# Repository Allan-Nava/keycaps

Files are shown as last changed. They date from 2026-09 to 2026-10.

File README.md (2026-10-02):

# keycaps

Replacement keycaps for mechanical keyboards, modelled parametrically in
OpenSCAD, validated geometrically before anything gets sliced, and documented
with the provenance of every single dimension.

## Why it is built this way

Replacement keycaps fail for boring reasons: a stem 0.1 mm too tight, a
stabiliser hook 0.5 mm too high, a skirt that rubs the switch housing. So the
rule here is:

* **every dimension carries a provenance tag** — `[SRC]` from a source,
  `[DER]` derived from one, `[EST]` closest standard value, `[FIT]` fit-critical
  *and* unverifiable online, so it has to be measured off the original part;
* **nothing is asserted that was not found** — if a number could not be sourced
  it is marked as an estimate, never dressed up as confirmed;
* **checks are boolean probes, not eyeballing** — a solid shaped like a real MX
  cross is pushed into the socket and the interference volume is measured;
* **the drawing is generated from the rendered solid**, and the Python tooling
  reads its dimensions back out of the render, so neither can drift from the
  model.

## Layout

```
lib/keycap_common.scad      shared geometry: shell, dish, sculpt, MX cross
                            socket, Costar hook, ribs, relief legends
tools/build_and_validate.py render + write the print-ready STL + 20 checks
tools/make_drawing.py       dimensioned 4-view drawing from the solid
tools/scadparams.py         reads ##PARAM echoes back out of a render

<keyboard>/<key>.scad       parameters + provenance for one key
<keyboard>/<key>.stl        production STL, already in print orientation
<keyboard>/<key>-drawing.*  svg / pdf / png
<keyboard>/README.md        provenance, critical dimensions, print settings
<keyboard>/VALIDATION-<key>.txt   output of the last validation run
```

## Keyboards

| keyboard | key | status |
|---|---|---|
| [`ozone-strike-battle`](ozone-strike-battle/) | left Shift — **ISO 1.25u** and ANSI 2.25u | **done** — all checks pass. ISO prints as-is; the ANSI one has one `[FIT]` dimension to measure first |
| [`asus-rog-falchion-ace`](asus-rog-falchion-ace/) | left Shift ISO 1.25u, G, ↑ — ITA layout | **done** — all checks pass; profile is estimated, nothing was measured |

## Usage

```bash
python3 tools/build_and_validate.py ozone-strike-battle/left-shift-iso.scad
python3 tools/make_drawing.py       ozone-strike-battle/left-shift-iso.scad
```

Or `make` (builds and validates everything, then the drawings).

### Requirements

* `openscad` with the manifold backend. On macOS the stable cask is disabled
  (Gatekeeper), so use the snapshot: `brew install --cask openscad@snapshot`
* Python: `trimesh manifold3d numpy rtree matplotlib`

```bash
python3 -m venv .venv && .venv/bin/pip install trimesh manifold3d numpy rtree matplotlib
```

## Printed

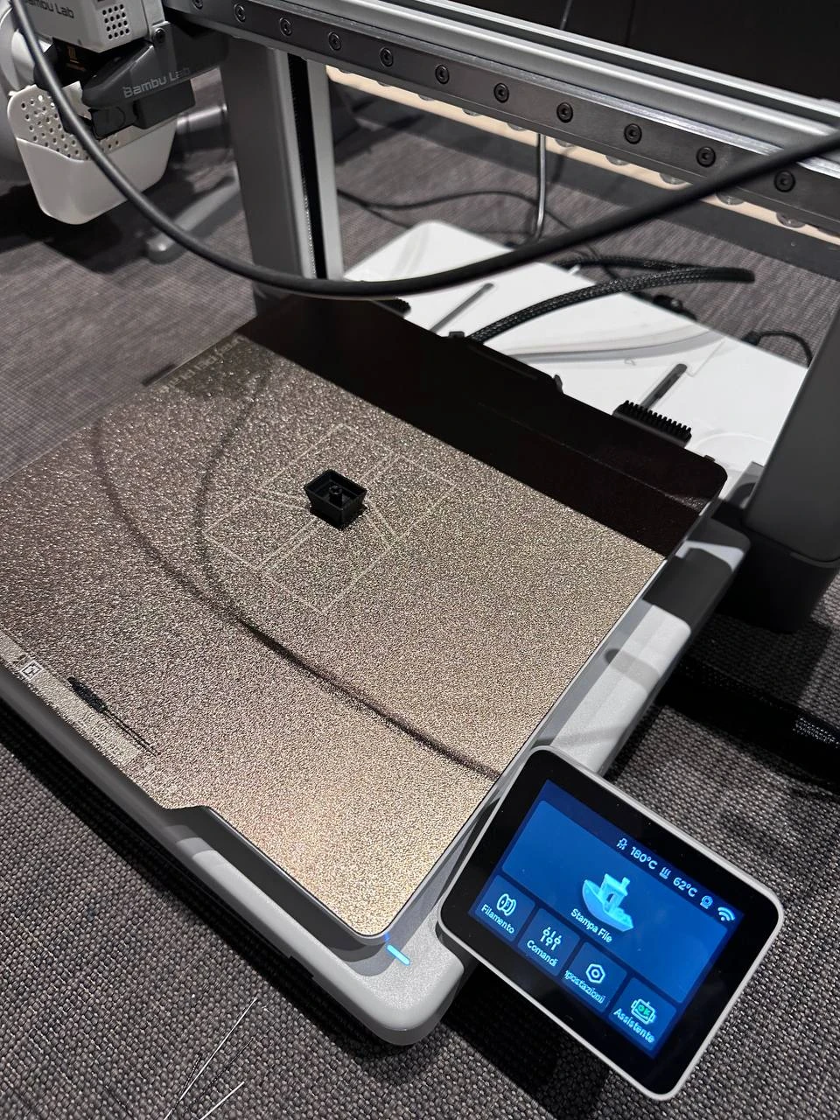
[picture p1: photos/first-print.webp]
first print


The first model off the plate, 2026-10-02. It sliced with no support in the
committed orientation, which is the part the geometric checks predicted.

What this photo does **not** prove is the part that matters: whether it seats
on a real switch. Until a cap has been pushed onto one, the stem clearances
are still the estimates the provenance tables say they are. See
[`photos/`](photos/) for what a print does and does not establish.

## The catalogue

**<https://allan-nava.github.io/keycaps/>** — every model with its dimensions,
its weight in PLA, its drawing and a direct STL download.

The page is generated by [`tools/make_site.py`](tools/make_site.py) from the
JSON the validator writes, so it cannot state a dimension the checks did not
measure, and it only deploys after `validate` is green.

## CI

Three workflows.

**[`validate`](.github/workflows/validate.yml)** is the merge gate. It discovers
every `<keyboard>/<key>.scad` by itself (no list to maintain), renders each one
on a matrix job and runs the full check suite, then verifies that the
**committed STL still matches the model** — which is what catches "edited the
.scad, forgot to regenerate". That last comparison is on the bounding box and
the volume, not on bytes: tessellation and font substitution differ between a
Mac and a runner, so a byte compare would be permanently red. A `repo hygiene`
job checks in parallel that every key has an STL, a validation report and a
README. On a green push to `main` the printable files go up as a single
downloadable artifact, so nobody needs OpenSCAD to get them.

**[`pages`](.github/workflows/pages.yml)** builds and publishes the
catalogue, and refuses to run when `validate` failed: publishing a keycap that
does not pass its own checks would be worse than publishing nothing.

**[`self-test`](.github/workflows/selftest.yml)** exists because a check that
cannot fail is decoration. It breaks a known-good keycap on purpose — socket
bored out, cap wider than its own pitch, walls thickened past the switch,
Costar bore under the wire diameter, socket undersized — and asserts that *the
specific check meant to catch that defect* is the one reporting FAIL, not
merely that something went wrong. It runs whenever `tools/` or `lib/` changes,
which is where a check can quietly stop working.

The drawings are byte-reproducible: matplotlib is told not to stamp a creation
date, so regenerating a drawing that did not change produces no diff, and "is
the committed artefact current" stays an answerable question.

Run both locally:

```bash
python3 tools/build_and_validate.py --check <keyboard>/<key>.scad
python3 tools/repo_lint.py
python3 tools/selftest.py
```

Ubuntu ships OpenSCAD 2021.01, which predates `--backend=manifold`, so CI
installs a dated snapshot AppImage — pinned for reproducibility, with a warned
fallback to the newest when that snapshot rotates off the server. See
[`.github/scripts/install-openscad.sh`](.github/scripts/install-openscad.sh).

## Adding a key

1. `cp ozone-strike-battle/left-shift-iso.scad <keyboard>/<key>.scad` and strip it
   back to the parameters that actually differ. With more than one key on the
   same board, put the shared parameters in `<keyboard>/profile.inc.scad` —
   files matching `*.inc.scad` are not treated as keys by the tools.
2. Override only what you know. Anything left at the library default is an
   estimate by definition — tag it `[EST]` and say so in the README.
3. Run the validator. It refuses to pass on an unimplemented stabiliser style
   rather than silently skipping the check.
4. Write `<keyboard>/README.md` with the provenance table, and list what could
   **not** be verified. That section is the point of the repo.

## Two OpenSCAD traps this repo walked into

**An included file's *variable* cannot be referenced from an assignment in the
including file.** OpenSCAD reports `Ignoring unknown variable` and leaves
`undef`, which then propagates silently through the whole model. A *function*
from the same include resolves fine, which is why per-row values are exposed as
`fa_h(row)` / `fa_tilt(row)` rather than `FA_R4_H`. Module arguments
(`text(font = fa_font())`) are evaluated later and are also fine.

**A relief legend whose outline is tangent to the stem boss's cylindrical seam
produces sliver faces and a non-manifold mesh** — clean in OpenSCAD's own
report, broken on reload. That is why `stem_top_gap` stops the boss 0.90 mm
below the top surface: the boss stays fused to the roof and its seam never
reaches the surface where a legend sits.

## Licence

[MIT](LICENSE) — the OpenSCAD sources, the Python tooling and the generated
STLs alike. Print them, sell the prints, fork the lot; just keep the notice.

**No warranty, and that matters here more than usual**: several dimensions in
every model are estimates, and each keyboard's README says exactly which ones.
Test-fit a print on a spare switch before committing to a set.

## Stabiliser styles

`lib/keycap_common.scad` implements:

* `"none"` — 1u keys and anything unstabilised.
* `"costar"` — wire stabiliser with integrated hooks, so the original white
  Costar inserts are not needed. Used by the Strike Battle.

`"cherry"` (clip-in plastic stabiliser stems, what most modern boards use) is
deliberately **not implemented**: the housing and stem dimensions have to be
measured or sourced first. A wrong stabiliser stem binds the key, so it is
better to have nothing there than a plausible guess.

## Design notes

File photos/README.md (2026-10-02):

# Physical evidence

Everything else in this repo is geometry: a solid is rendered, boolean probes
are pushed into it, and the numbers are recorded. That catches a great deal —
a socket that would not accept an MX cross, a cap wider than its own key
pitch, an overhang that would need support — and it cannot catch anything
that only exists once plastic cools.

So this directory is for photographs of the models as actually printed, kept
separate from the validation output on purpose. **A photo is not a check.**
It is the thing a check cannot be.

## What a print proves, and what it does not

| | |
|---|---|
| it printed | the geometry is sliceable, the orientation works, no support was needed |
| it looks right | the profile, the dish and the legend are what the drawing said |
| **it fits** | **only confirmed by pushing it onto a real switch** |
| it survives | only confirmed by typing on it for a while |

The third row is the one that matters, and it is the one a photograph of a
build plate cannot answer. Until a cap has been seated on a switch, the
tolerances in `cross_clr_w` / `cross_clr_t` are still estimates — see the
provenance tables in each keyboard's README.

## Index

| photo | model | printed on | fit confirmed |
|---|---|---|---|
| [`first-print.webp`](first-print.webp) | 1u cap, Bambu Lab, black filament | 2026-10-02 | not yet |

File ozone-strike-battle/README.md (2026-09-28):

# Ozone Strike Battle — replacement LEFT SHIFT keycap

Cherry MX cross stem, OEM-like sculpt, designed for FDM in PLA / PETG.
**Two variants, and they are not interchangeable — pick by your layout:**

| variant | file | size | stabiliser | fits |
|---|---|---|---|---|
| **ISO** | `left-shift-iso.stl` | **1.25u**, 22.85 × 18.10 × 11.39 | **none** | ITA / UK / DE — a `<>` or `\|` key sits next to the left Shift, and the Enter is the tall L |
| ANSI | `left-shift-ansi.stl` | 2.25u, 41.90 × 18.10 × 11.39 | Costar wire, integrated hooks | US — Z is directly next to the left Shift, and the Enter is a flat 2.25u bar |

The board this was built for is an **ISO Italian** Strike Battle. ITA, UK and DE
share the same 1.25u left Shift — only the glyph on the key next to it differs
(`<>` on ITA, `\|` on UK) — so the ISO cap covers all three.

Look at your own board before printing. On an ISO keyboard the left Shift is
split into a 1.25u Shift plus the extra `<>` key, so it is short and carries no
stabiliser at all; on ANSI it is one 2.25u key on a 2u Costar wire.

The **ISO cap is the simpler of the two**: no stabiliser means the one
fit-critical, unverifiable dimension of the ANSI cap (§1) does not exist for it.
If you are on ISO, you can print straight away.

| file | what it is |
|---|---|
| `left-shift-iso.*` / `left-shift-ansi.*` | STL, parametric source, dimensioned drawing, renders |
| `VALIDATION-left-shift-iso.txt` / `-ansi.txt` | validation output — **ALL CHECKS PASSED** for both |

Rebuild:

```bash
python3 ../tools/build_and_validate.py left-shift-iso.scad
python3 ../tools/make_drawing.py       left-shift-iso.scad
```

Everything below — provenance, profile, print settings — applies to both caps.
The parts that are specific to the Costar stabiliser are marked as such and are
simply absent from the ISO variant.

---

## 1. ANSI variant only — the one dimension I could not verify

*(The ISO 1.25u cap has no stabiliser, so none of this section applies to it.)*

**`wire_z = 4.20 mm`** — the height of the Costar wire stub above the bottom rim
of the keycap. This is the single fit-critical dimension that is **not documented
anywhere online**, not for the Strike Battle and not for Costar stabilisers in
general. I did not find a drawing, a datasheet or a measured teardown.

If it is wrong, the Shift key will bind or the wire will not seat.

**Measure it on your original cap** (or on the keyboard, with the stabiliser
installed and the cap off): the distance from the plane of the keycap's bottom
rim to the centre of the horizontal wire stub. Then edit one line:

```openscad
wire_z       = 4.20;    // <- your measurement
```

and re-render. Everything else in the stabiliser interface (bore, throat,
lead-in, block) follows from it automatically.

Two related things I also could not confirm, and how the design sidesteps them:

* **Whether the original Ozone cap uses separate white Costar inserts or moulded-in
  hooks.** The Deskthority Costar page shows Filco inserts but gives no
  dimensions, and no Strike Battle underside teardown photo with measurements
  exists that I could find. → This design uses **integrated hooks**, so you do
  not need the original inserts at all. If you would rather reuse them, the hook
  block is a single module in the `.scad` and can be replaced with a pocket.
* **Which way the wire stub points** (inwards, towards the key centre, or
  outwards). → The bore is a **through-hole along X across the whole hook block**,
  so it works either way.

---

## 2. Critical dimensions

All in mm. Origin = key centre, z = 0 at the bottom rim of the skirt, +Y towards
the back of the keyboard.

### Outside

| dimension | value | tag |
|---|---|---|
| 1u pitch | 19.05 | SRC |
| key size | 2.25u → 42.8625 pitch | SRC |
| body width (plastic) | **41.90** | DER |
| body depth (plastic) | **18.10** | DER |
| gap to Caps Lock / Z | 0.48 per side | DER |
| height at the key centre (top of the dish) | 9.60 | EST |
| overall height (highest point, at the back edge) | 11.39 *(measured on the solid)* | DER |
| row tilt (back edge higher) | 6° | EST |
| top plate | 37.70 × 13.90 | EST |
| side draft | 2.10 per side over 10.05 → ~11.8° | EST |
| corner radius, skirt / top | R1.20 / R2.60 | EST |
| top edge chamfer | 0.60 | EST |
| dish | cylindrical, R28, 1.05 deep, axis along X | EST |
| legend | embossed up-arrow, 0.45 high, at x = −13.5 | EST |

### Shell

| dimension | value | tag |
|---|---|---|
| side wall | 1.55 | EST |
| skirt wall (below z = 4.20, blending back over 0.80) | 1.15 | EST |
| roof under the dish | 1.70 | EST |
| diagonal ribs | 4 × 1.20 thick, starting at z = 5.00 | EST |

The skirt is deliberately thinner than the rest: it keeps the interior at least
as roomy as a stock OEM cap all the way around the switch housing (validated —
see §4).

### Cherry MX stem

| dimension | value | tag |
|---|---|---|
| cross, switch side | 4.10 × 1.17 | SRC |
| socket, as modelled | **4.22 × 1.39** | DER (SRC + tolerance) |
| FDM clearance added | +0.12 across, +0.22 through | EST |
| socket depth | 4.30 (MX stem is ~3.7 tall) | EST / SRC |
| chamfered lead-in at the mouth | 0.45 | EST |
| stem boss OD | 5.60 (stock ≈ 5.5) | EST |
| boss bottom face | z = 0.50 | EST |

### Costar stabiliser

| dimension | value | tag |
|---|---|---|
| mount spacing | 1.25u = **23.8125** (±11.90625) | SRC → DER |
| wire diameter assumed | 1.30 (quoted 1.2 + margin) | SRC / EST |
| bore | Ø1.65 (0.35 diametral clearance), through the block along X | EST |
| wire height above the rim | **4.20** | **FIT — unverified** |
| snap throat | 1.20 wide, straight for 0.60 below the bore, then flared +1.6 | EST |
| hook block | 6.00 (X) × 5.50 (Y), bottom face at z = 2.60 | EST |

---

## 3. Where each number came from

### Taken from a source

* **19.05 mm per unit; left Shift = 2.25u; left Shift stabiliser = 2u** —
  [Omnitype keycap sizes](https://intercom.help/omnitype/en/articles/5121683-keycap-sizes).
  That page gives no millimetres, only units.
* **2u stabiliser mounts are 1.25u apart** → 1.25 × 19.05 = **23.8125 mm**, i.e.
  ±11.90625 from the stem. Stated as "stabilizers are the same for 2u, 2.25u and
  2.75u keys with 1.25u between mounts" in the Cherry MX plate-measurement
  discussion on [Deskthority](https://deskthority.net/viewtopic.php?t=20144).
* **Cherry MX cross: 4.1 mm wide, 1.17 mm thick** — the Cherry MX drawing, as
  cited by the [MX keycap tolerance test](https://www.thingiverse.com/thing:4397634)
  and the [Cherry MX mount thread](https://deskthority.net/viewtopic.php?t=11183).
  The same sources list the common keycap-side variants 4.0 × 1.0 (Signature
  Plastics) and 4.1 × 1.35.
* **MX stem ~3.7 mm tall, 4.0 mm travel** — [Telcontar KBK, Cherry MX](https://telcontar.net/KBK/Cherry/MX).
* **This keyboard specifically** — the [Test-Gear review](https://www.test-gear.pl/testy-i-recenzje/klawiatury/ozone-strike-battle/):
  Cherry MX switches, **Costar-type stabilisers under the long keys**, ABS
  keycaps, "cylindrical shape with rounded edges", keycap **heights 9–11 mm**,
  **right Shift measured at 51 mm**, **spacebar at 118 mm**. Plus the
  [Ozone specification page](https://ozonegaming.com/en/pages/especificaciones-strike-battle):
  87 keys, ABS 94HB keycaps, backlight with brightness steps (so there *is* an
  LED in the switch's north window to clear).
* **Costar 2u wire quoted at 1.2 mm diameter** — from a stabiliser listing found
  via search. Single, weak source; treated as 1.30 with margin.
* **FDM tolerance guidance: cut-outs need ~0.1 mm added** — the MX tolerance
  test above (0.05 for SLA, >0.1 for FDM).

### Derived from those

* **41.90 body width.** The review's 51 mm right Shift (2.75u pitch = 52.3875)
  and 118 mm spacebar (6.25u pitch = 119.0625) both fit an inter-cap gap of
  ≈1.0 mm: 52.3875 − 1.0 = 51.39 → "51", and 119.0625 − 1.0 = 118.06 → "118".
  A gap of 0.85 (the usual 18.2 mm 1u body) would give 51.5 and 118.2, which
  rounds to 52 and 118 — a worse fit to the measurements. I used 0.96, giving
  41.90 for 2.25u. The review's figures are ruler measurements, so treat this as
  ±0.3 mm; it only affects the gap to Caps Lock and Z, not the fit.
* **18.10 body depth** — same reasoning on the 1u axis (gap 0.95).
* **±11.90625 stabiliser positions** — 1.25u/2.
* **4.22 × 1.39 socket** — the 4.10 × 1.17 cross plus FDM clearance.

### Estimated (closest standard value, not verified for this board)

Everything tagged `[EST]` in §2: the sculpt (heights, tilt, taper, radii, dish),
all wall and roof thicknesses, the rib and hook-block geometry, socket depth,
stem boss diameter, and the print tolerances. The only anchor for the sculpt is
the review's "9–11 mm" height range and "cylindrical" top, which the model
matches (9.60 at the dish centre, 11.60 at the back edge, cylindrical R28 dish).

OEM row heights are quoted inconsistently across vendor pages (10.3–13.3 mm
depending on who is measuring what), so I did not use them.

### Cannot be verified from online documentation

1. **`wire_z` = 4.20** — see §1. The one that matters.
2. Whether the original cap uses **separate Costar inserts** and, if so, their
   socket dimensions. No dimensioned source exists.
3. The **direction of the wire stub**. Worked around with a through-bore.
4. The exact **Cherry MX top-housing envelope above the plate** and the LED
   height. Because of this, the switch-clearance check is *relative* (see §4)
   rather than against an invented envelope.

---

## 4. Validation (all automated, see `VALIDATION.txt`)

Every check is a boolean probe against the rendered solid, not a visual check.

```
mesh        watertight, single closed solid, euler = 2, volume 2731.7 mm^3
size        41.903 x 18.100 x 11.39 ; fits the 2.25u x 1u pitch with
            0.48 mm per side to Caps Lock / Z and 0.47 mm front / back
stem        a nominal 4.10 x 1.17 MX cross enters with zero interference;
            a 4.40 x 1.47 probe does clash -> the socket is not oversized;
            socket centroid X = 0.000, Y = 0.000 -> centred
Costar      bores clear at x = +-11.90625 ; throat (1.20) open to the underside ;
            seated wire free to move +-0.15 mm inside the bore ;
            wire arm clears the whole cavity from |x| = 3.2 to 18.5 (misses the
            stem boss, the ribs and the walls) ; 0.02 mm^3 of intentional
            throat interference = a light snap
switch/LED  interior never tighter than a stock OEM cap (18.20 outer, 1.20 wall,
            same draft) anywhere from z = 0.2 to 5.0 -> worst margin -0.00 mm ;
            the north LED column (4 x 2.2 mm at y = 2.9..5.1, 7 mm tall) is clear
printing    sits flat on z = 0 ; first layer is the top-plate rim, not a point ;
            4.6 mm^2 of true overhang (the two bore roofs, 6 mm wide bridges) ;
            532 mm^2 of dish bridged over the bed, anchored all round ;
            1373 mm^2 of drafted wall at <= 12.6 deg from vertical
```

The switch-clearance check is deliberately **relative**: since the MX housing
envelope above the plate is not reliably documented, the model is required to be
no tighter anywhere than a stock OEM 1u cap's interior. It passes at every height
from 0.2 to 5.0 mm.

---

## 5. Printing

The STL is already oriented: **top plate flat on the bed, open side up**. Nothing
needs support — the dish is a 1.05 mm deep pocket sitting directly on the bed and
is bridged from its own rim, and the two wire bores are 6 mm bridges.

### PLA

| setting | value | why |
|---|---|---|
| **layer height** | **0.12 mm** (0.16 acceptable) | the cross socket is 1.39 mm through — thin layers keep it dimensionally honest |
| first layer | 0.20 mm | rim-only contact |
| **wall count** | **3** (0.4 nozzle, 0.42 width ≈ 1.26 mm) | matches the 1.15 mm skirt and the 1.55 mm wall without leaving gaps; 4 walls would over-stuff the skirt |
| **infill** | **100 %** | the part is nearly all perimeters; 100 % only fills the stem boss and hook blocks, where the strength is needed, and costs ≈2.7 cm³ total |
| top / bottom layers | 5 / 5 | |
| nozzle / bed | 205–215 °C / 60 °C | |
| cooling | 100 % from layer 3 | |
| supports | **none** | |
| brim | 5 mm, or a raft if your first layer is fussy | the bed contact is only the top-plate rim |
| seam | aligned, placed at a rear corner | keeps the visible top clean |
| horizontal expansion / XY compensation | 0 | the clearances are already in the model |

**PETG:** same, but 230–245 °C, 50 % cooling, and add 0.05 mm to
`cross_clr_w` / `cross_clr_t` — PETG swells more on the way out of the nozzle.

### Test fit first

Print the model once and try the stem on a spare switch before committing to the
stabiliser geometry.

* **too tight** → raise `cross_clr_w` / `cross_clr_t` by 0.05
* **too loose / wobbles** → lower them by 0.05
* **wire will not snap in** → raise `throat_w` toward `stab_wire_d`
* **wire rattles** → lower `bore_clr` to 0.25

### Fitting

1. Press the cap onto the switch far enough to locate the stem.
2. Line the two wire stubs up with the throats and push straight down — each
   stub snaps up into its bore.
3. Press home on the stem last.

To remove, pull evenly from both ends, not from one corner.

---

## 6. Deliberate departures from the original

* **Integrated Costar hooks instead of separate inserts** — you do not need the
  original white clips, and it removes an unverifiable set of socket dimensions.
* **Stem boss Ø5.60 instead of the stock ≈5.5** — a little more meat around the
  cross for FDM, while still clearing the in-switch LED at the north face.
* **Thinner skirt (1.15) than the upper wall (1.55)** — keeps the interior at
  least as roomy as a stock cap around the switch housing while leaving a wall
  thick enough to print at 3 perimeters higher up.
* **Embossed arrow instead of the original's laser-cut legend** — a single-colour
  FDM print cannot reproduce a dye-sub two-layer legend. Set
  `legend_arrow = false` for a blank cap.
* Functional compatibility was prioritised over cosmetic similarity throughout,
  as requested.

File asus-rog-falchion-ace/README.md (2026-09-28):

# ASUS ROG Falchion Ace — replacement keycaps (ISO/ITA)

Three keys, none of them stabilised: **left Shift (ISO 1.25u)**, **G (1u)** and
**↑ (1u)**. MX-compatible cross stem, Cherry-like sculpt, for FDM in PLA/PETG.

| key | file | size | row | overall height | STL |
|---|---|---|---|---|---|
| left Shift | `left-shift.scad` | 1.25u | ZXCV | 9.97 mm | `left-shift.stl` |
| ↑ | `arrow-up.scad` | 1u | ZXCV | 9.86 mm | `arrow-up.stl` |
| G | `g.scad` | 1u | home (ASDF) | 8.50 mm | `g.stl` |

All three pass every check — `VALIDATION-<key>.txt`. Shared parameters live in
`profile.inc.scad`; the geometry itself is in [`../lib/keycap_common.scad`](../lib/keycap_common.scad).

```bash
python3 ../tools/build_and_validate.py left-shift.scad
python3 ../tools/make_drawing.py       left-shift.scad
```

---

## 1. What is confirmed, and by what

### From the product photo supplied by the user

The user's board is the **Italian** one. The photo they supplied happens to show
the DE/QWERTZ variant, which they confirmed matches their layout physically —
and it does: ITA and DE differ only in which glyphs are printed on *other* keys
(QWERTZ vs QWERTY, Ü Ö Ä vs Ì Ò À), never in key sizes or positions. For the
three keys modelled here — ⇧, G and ↑ — the two layouts are identical.

The photo settles three things a spec sheet does not:

* **left Shift is 1.25u**, with the extra ISO `<>|` key next to it — so, unlike
  the ANSI 2.25u left Shift in `../ozone-strike-battle/`, **it is not
  stabilised**;
* **↑ sits in the ZXCV row**, to the right of the right Shift, so it takes that
  row's sculpt, not the bottom row's;
* legends on the alphas are centred, and the board is ISO (tall L-shaped Enter).

### From sources

* **ROG NX stem is MX-compatible**: ASUS states the "standard cross-shaped stem
  design ensures compatibility with most keycaps", so the Cherry MX cross
  (4.10 × 1.17) applies. [ROG NX switch page](https://rog.asus.com/content/rog-keyboard-switch/)
* **No LED enters the keycap.** Per-key RGB comes from "centrally placed RGB
  LEDs" on the PCB, shining through the switch's **hollow stem** and its
  transparent polycarbonate upper housing. So there is nothing to clear inside
  the cap — `led_clear_h = 0`, and the validator says so explicitly instead of
  silently skipping. [ROG NX switch page](https://rog.asus.com/content/rog-keyboard-switch/)
* **Cherry profile, PBT doubleshot**, "mid-height keycaps". [ASUS product page](https://rog.asus.com/keyboards/keyboards/compact/rog-falchion-ace-model/),
  [review](https://basic-tutorials.com/reviews/peripherals/asus-rog-falchion-ace/)
* **65 %, 68 keys, 306 mm long.** ASUS product page.
* Cherry MX cross 4.10 × 1.17: the Cherry drawing, via the
  [MX tolerance test](https://www.thingiverse.com/thing:4397634) and
  [Deskthority](https://deskthority.net/viewtopic.php?t=11183).

---

## 2. The profile — how the heights were arrived at

**This is the weak part of the model, and it is cosmetic, not fit-critical.**

ASUS publishes no keycap drawing. The public Cherry-profile guides contradict
each other badly: one gives R1 9.81 / R2 7.85 / R3 7.22 / R4 8.59 mm with the
home row lowest and calls the sculpt spherical (it is cylindrical); another
gives 9.4 / 9.0 / 8.75 / 8.1 mm monotonically decreasing, with the home row
*not* lowest. They cannot both be right and I could not resolve which is.

So the numbers here are built from the one claim both sources agree on —
**Cherry is 1–2 mm lower than OEM across all rows** — plus this repo's own
validated OEM cap:

* `../ozone-strike-battle/left-shift-ansi` is a validated OEM ZXCV-row cap at
  **11.39 mm** overall → Cherry ZXCV ≈ 11.39 − 1.5 = **~9.9 mm**. Modelled:
  9.97 (1.25u) / 9.86 (1u).
* The **row-to-row delta** (1.37 mm between ZXCV and home) and the **tilts**
  (12° / 5°) come from the internally coherent source — the one where the home
  row is lowest and the tilt grows away from it, which is how a sculpted
  profile actually behaves. Home row → **8.50 mm** overall.

Every profile number is therefore `[EST]`. If you ever get a caliper on an
original cap, `profile.inc.scad` has `fa_h(row)` and `fa_tilt(row)` at the top —
two lines.

Same for the body size: no measurement exists for this board, so 1u is
**18.10 × 18.10 mm** (the common value for Cherry-profile sets), leaving 0.47 mm
of gap per side inside the 19.05 pitch.

---

## 3. Critical dimensions

mm, origin at the key centre, z = 0 at the bottom rim, +Y towards the back.

| | value | tag |
|---|---|---|
| 1u pitch | 19.05 | SRC |
| body, 1u | 18.10 × 18.10 | EST |
| body, 1.25u (left Shift) | 22.86 × 18.10 | DER |
| gap to the neighbouring caps | 0.47 per side | DER |
| top plate | body − 2 × 2.10 per side | EST |
| row tilt, ZXCV / home | 12° / 5° | EST |
| top plate height at centre, ZXCV / home | 8.52 / 7.99 | EST |
| dish | cylindrical, **axis along Y** (concave left-right), R25, 0.90 deep | EST |
| corner radius, skirt / top | R1.20 / R2.60 | EST |
| top edge chamfer | 0.60 | EST |
| side wall | 1.55 | EST |
| skirt wall (below z = 4.20) | 1.15 | EST |
| roof | 1.70 | EST |
| MX cross, switch side | 4.10 × 1.17 | SRC |
| socket as modelled | 4.22 × 1.39, 4.30 deep | DER |
| stem boss | Ø5.60, from z = 0.50, stopping 0.90 below the top surface | EST |
| stabiliser | none on all three keys | SRC (photo) |
| ribs | none — a 1u/1.25u roof is carried by four close walls | EST |
| legend relief | ⇧ and ↑ raised 0.40; **G engraved 0.40** | EST |

The dish axis differs from the Strike Battle cap on purpose: a 2u+ key is
concave front-to-back, a 1u/1.25u key is concave left-right.

The G is **engraved** rather than raised — it is a key you type on constantly
and a raised glyph is felt under the fingertip. The two arrows are raised, where
the relief doubles as a tactile marker. Either way a single-material FDM print
cannot reproduce the original's doubleshot legend, and **shine-through is not
reproducible at all**: these three caps will be dark while the rest of the board
lights up.

---

## 4. Validation

```
left-shift  22.863 x 18.100 x 9.97   1158.2 mm^3   all checks pass
arrow-up    18.100 x 18.100 x 9.86    957.9 mm^3   all checks pass
g           18.100 x 18.100 x 8.50    878.9 mm^3   all checks pass
```

For all three: watertight single solid (euler 2), a nominal 4.10 × 1.17 MX
cross enters with zero interference while a +0.30 probe does clash, socket
centred to 0.000, interior never tighter than a stock cap of the same sculpt,
**0.0 mm² of overhang past 45°**, and the dish bridged over the bed from its
own rim.

---

## 5. Printing

The STLs are already oriented: top plate flat on the bed, open side up, no
supports. Settings are the same as
[`../ozone-strike-battle/README.md` §5](../ozone-strike-battle/README.md):
**0.12 mm layers, 3 walls, 100 % infill**, 5 mm brim. These caps are small
(~1 cm³ each), so print all three at once.

Test the stem on a spare switch before printing the set. Too tight → raise
`cross_clr_w` / `cross_clr_t` by 0.05 in `profile.inc.scad`; too loose → lower
them. ROG NX is advertised with a "shorter stem", which the 4.30 mm socket
depth accommodates (a deeper socket is harmless); if the caps feel wobbly on
the switch rather than loose on the cross, that is the switch, not this model.

---

## 6. Still open

* **No original cap was measured** — the user asked for a model built from
  online sources only. The profile (§2) and the body size are the part that
  would change if one ever is measured.
* **The other Cherry-profile rows** are not defined: `fa_h()` / `fa_tilt()`
  only cover rows 3 and 4. Adding the number row or the bottom row means
  extending those two functions.
* **Stabilised keys on this board** (space, Backspace, right Shift, ISO Enter)
  still need the Cherry-style stabiliser stem, which `lib/keycap_common.scad`
  deliberately does not implement. See the root README.

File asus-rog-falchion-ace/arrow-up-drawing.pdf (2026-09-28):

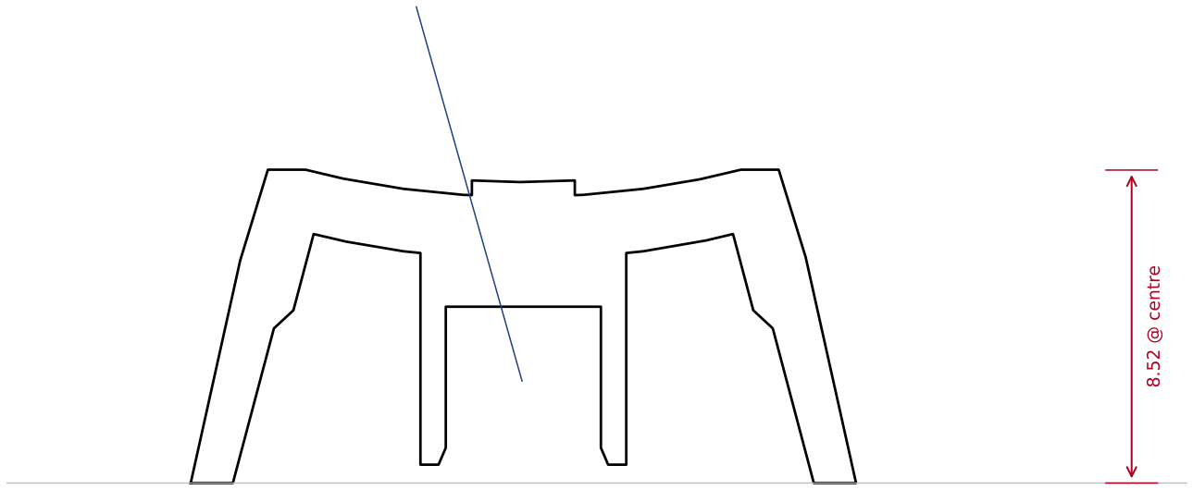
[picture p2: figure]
8.52 @ centre
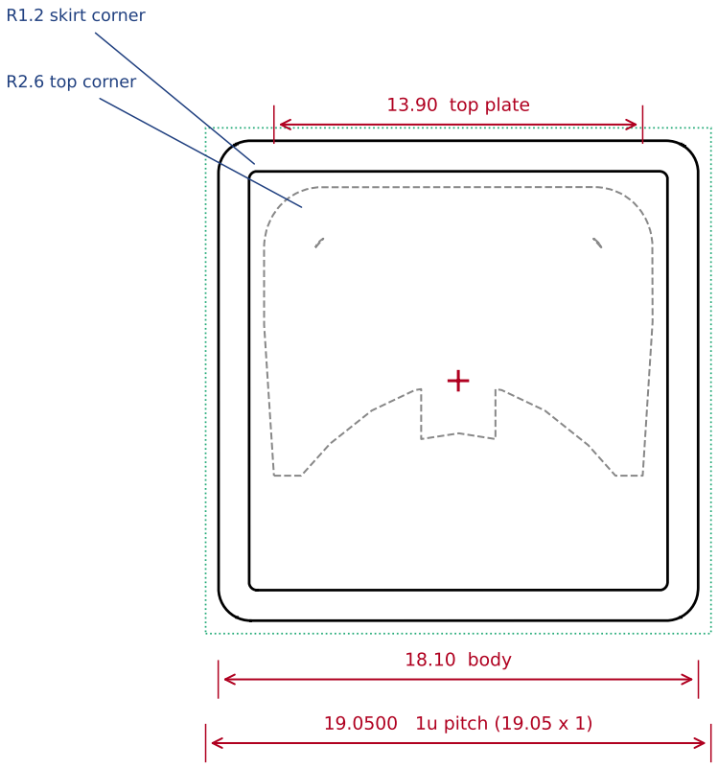
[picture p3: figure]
18.10 body; 19.0500 1u pitch (19.05 x 1); 13.90 top plate; R1.2 skirt corner; R2.6 top corner

18.10

A PLAN (top)
outline at the skirt and at the top plate

18.10

MX cross socket 4.22 x 1.39, 4.3 deep

B SECTION Y = 0 (front, through the stem)

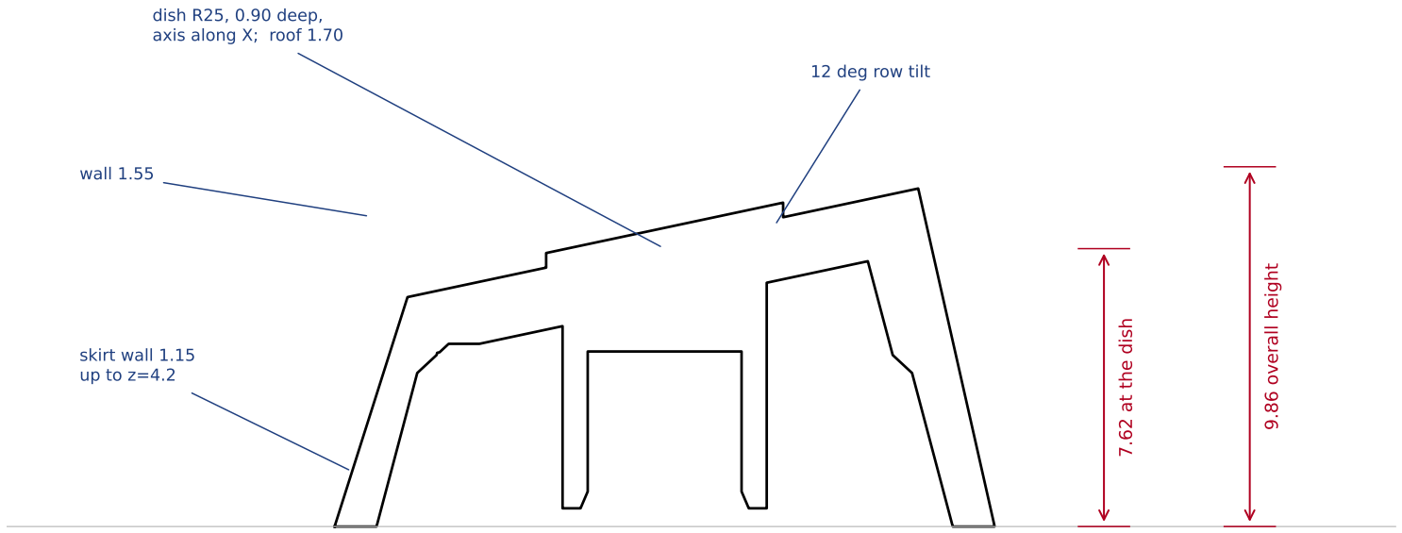
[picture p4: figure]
7.62 at the dish; 9.86 overall height; dish R25, 0.90 deep, axis along X; roof 1.70; wall 1.55; skirt wall 1.15 up to z=4.2; 12 deg row tilt

18.10

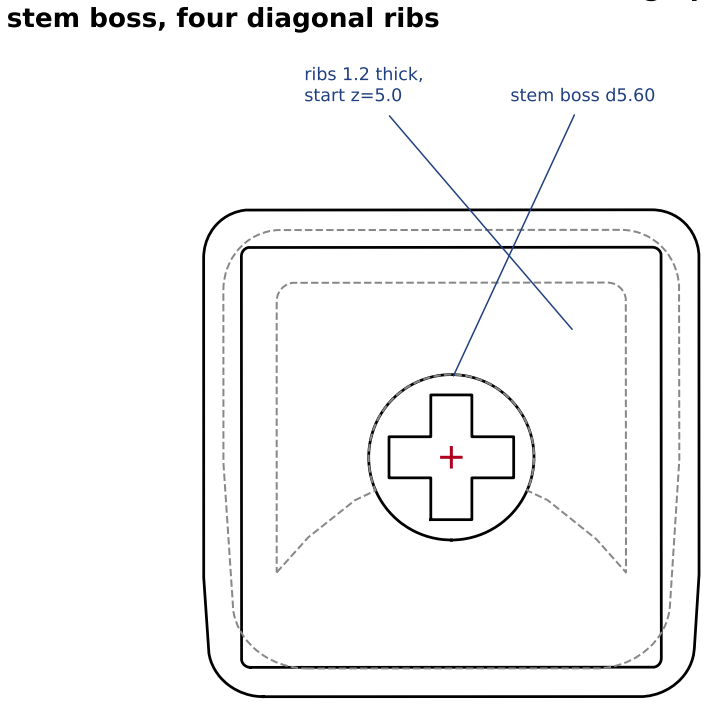
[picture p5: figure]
stem boss d5.60; ribs 1.2 thick, start z=5.0; stem boss, four diagonal ribs

C SECTION X = 0 (side, front of the keyboard to the left) OEM-style sculpt: top plate tilted back, cylindrical dish

D UNDERSIDE (section at z = 3.00, looking up) asus-rog-falchion-ace / arrow-up - 1u, MX cross stem | all dimensions in mm | dashed = hidden outline | dotted green = key pitch envelope

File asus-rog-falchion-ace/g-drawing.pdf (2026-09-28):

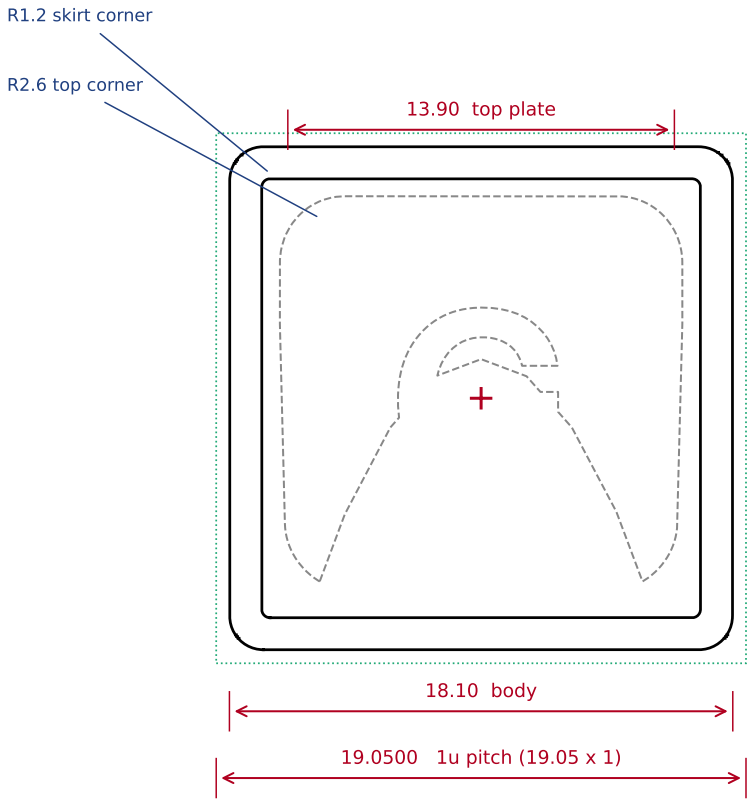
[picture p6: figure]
18.10 body; 19.0500 1u pitch (19.05 x 1); 13.90 top plate; R1.2 skirt corner; R2.6 top corner
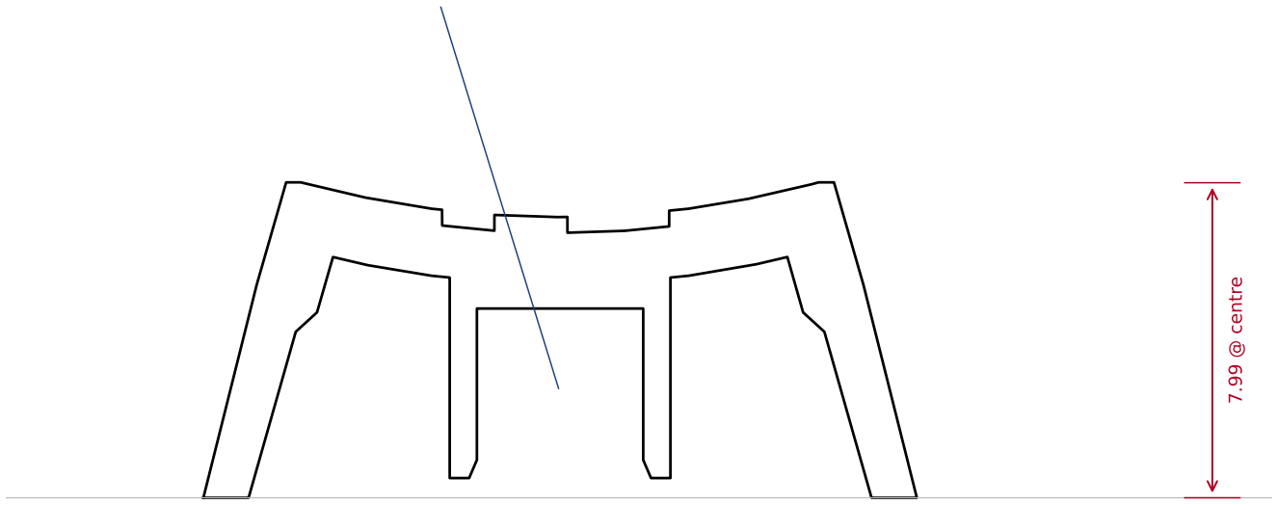
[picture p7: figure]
7.99 @ centre

18.10

A PLAN (top)
outline at the skirt and at the top plate

18.10

MX cross socket 4.22 x 1.39, 4.3 deep

B SECTION Y = 0 (front, through the stem)

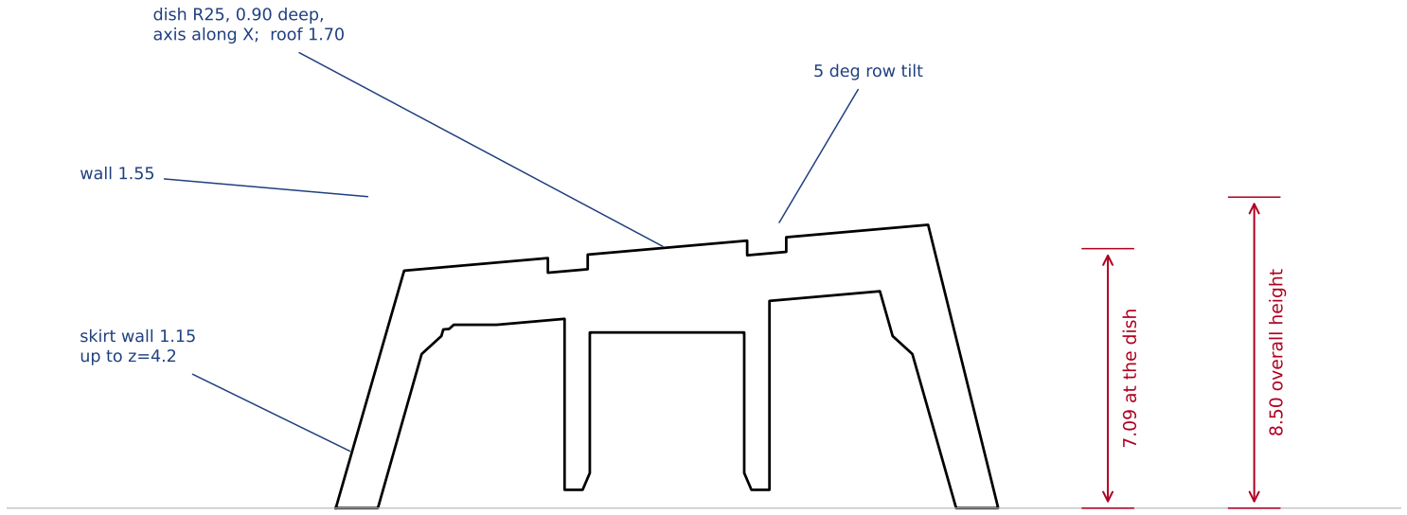
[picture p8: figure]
7.09 at the dish; 8.50 overall height; dish R25, 0.90 deep, axis along X; roof 1.70; wall 1.55; skirt wall 1.15 up to z=4.2; 5 deg row tilt

18.10

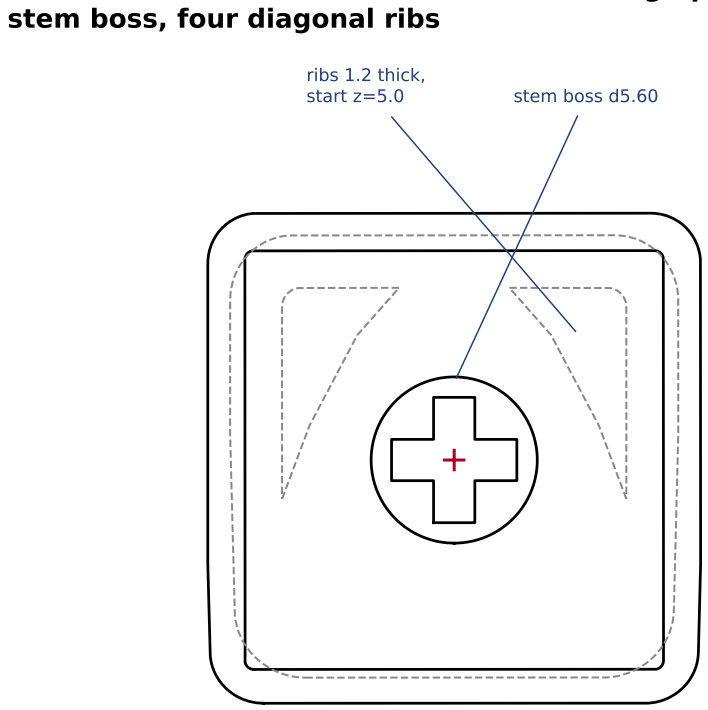
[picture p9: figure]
ribs 1.2 thick, start z=5.0; stem boss, four diagonal ribs

C SECTION X = 0 (side, front of the keyboard to the left)

OEM-style sculpt: top plate tilted back, cylindrical dish | stem boss d5.60 D UNDERSIDE (section at z = 3.00, looking up)
asus-rog-falchion-ace / g - 1u, MX cross stem | all dimensions in mm | dashed = hidden outline | dotted green = key pitch envelope

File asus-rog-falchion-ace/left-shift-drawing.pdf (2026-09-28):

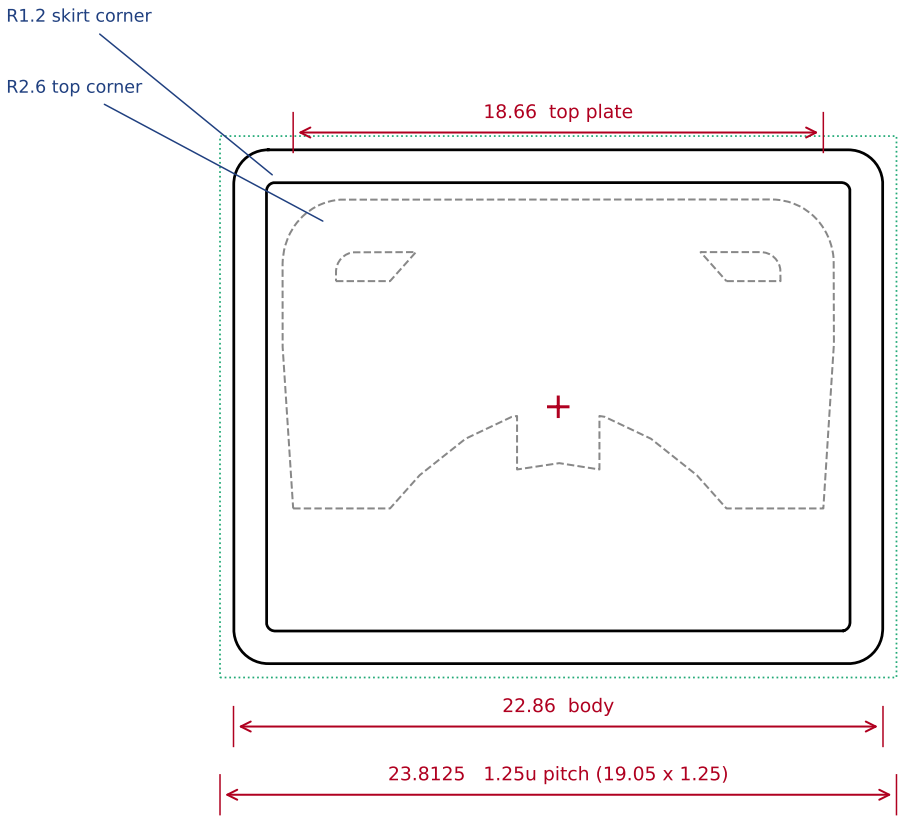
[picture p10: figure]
22.86 body; 23.8125 1.25u pitch (19.05 x 1.25); 18.66 top plate; R1.2 skirt corner; R2.6 top corner
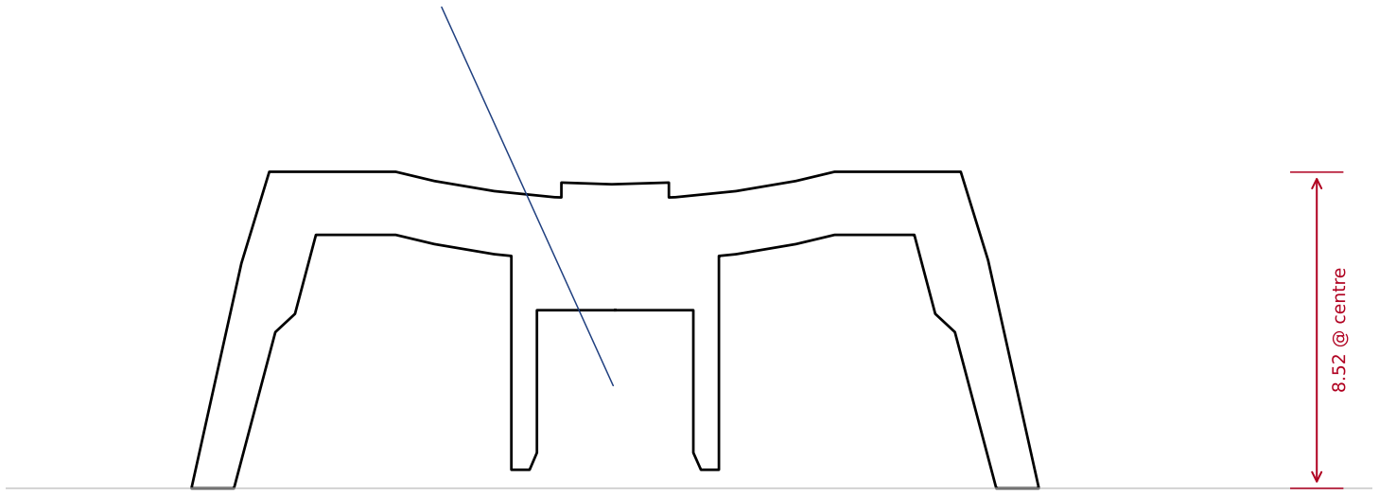
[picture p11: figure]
8.52 @ centre

18.10

A PLAN (top)
outline at the skirt and at the top plate

22.86

MX cross socket 4.22 x 1.39, 4.3 deep

B SECTION Y = 0 (front, through the stem)

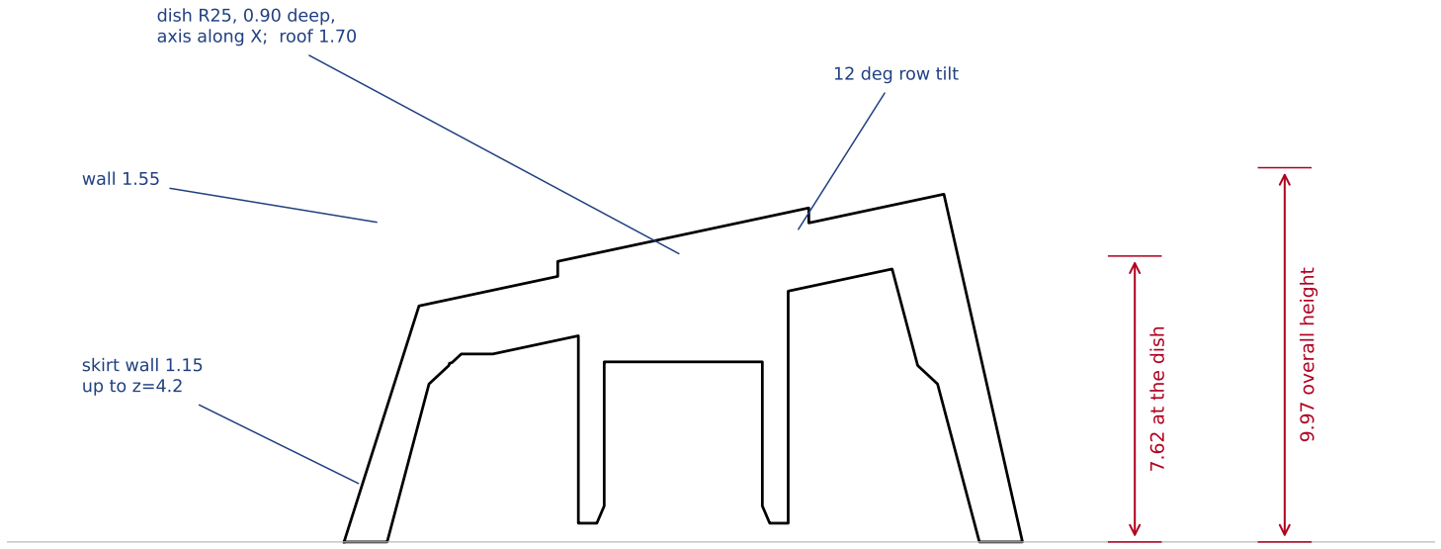
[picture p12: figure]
7.62 at the dish; 9.97 overall height; dish R25, 0.90 deep, axis along X; roof 1.70; wall 1.55; skirt wall 1.15 up to z=4.2; 12 deg row tilt

18.10

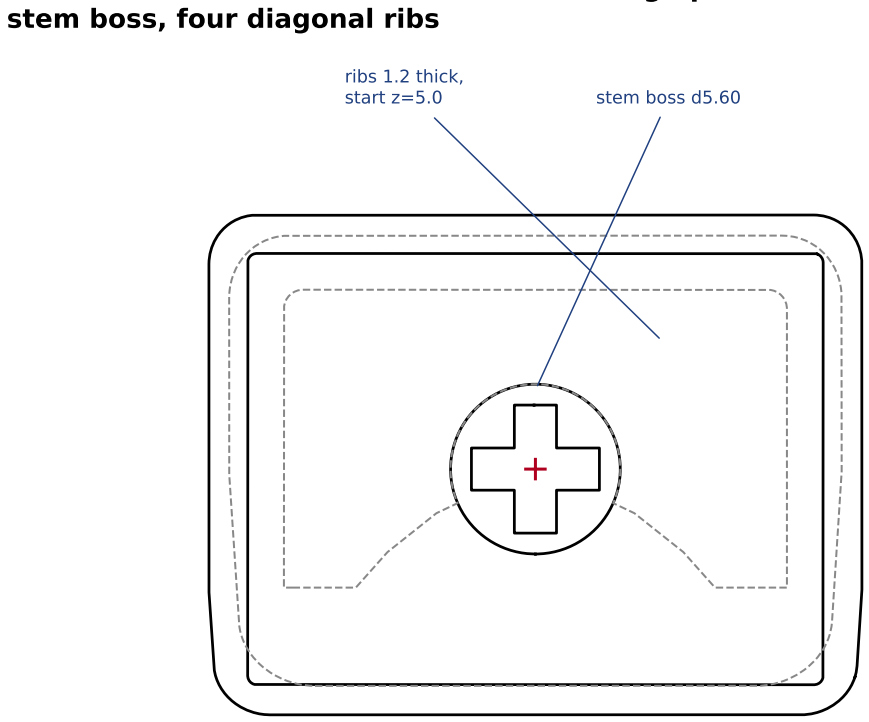
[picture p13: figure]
ribs 1.2 thick, start z=5.0; stem boss, four diagonal ribs

C SECTION X = 0 (side, front of the keyboard to the left)

OEM-style sculpt: top plate tilted back, cylindrical dish | stem boss d5.60 D UNDERSIDE (section at z = 3.00, looking up)
asus-rog-falchion-ace / left-shift - 1.25u, MX cross stem | all dimensions in mm | dashed = hidden outline | dotted green = key pitch envelope

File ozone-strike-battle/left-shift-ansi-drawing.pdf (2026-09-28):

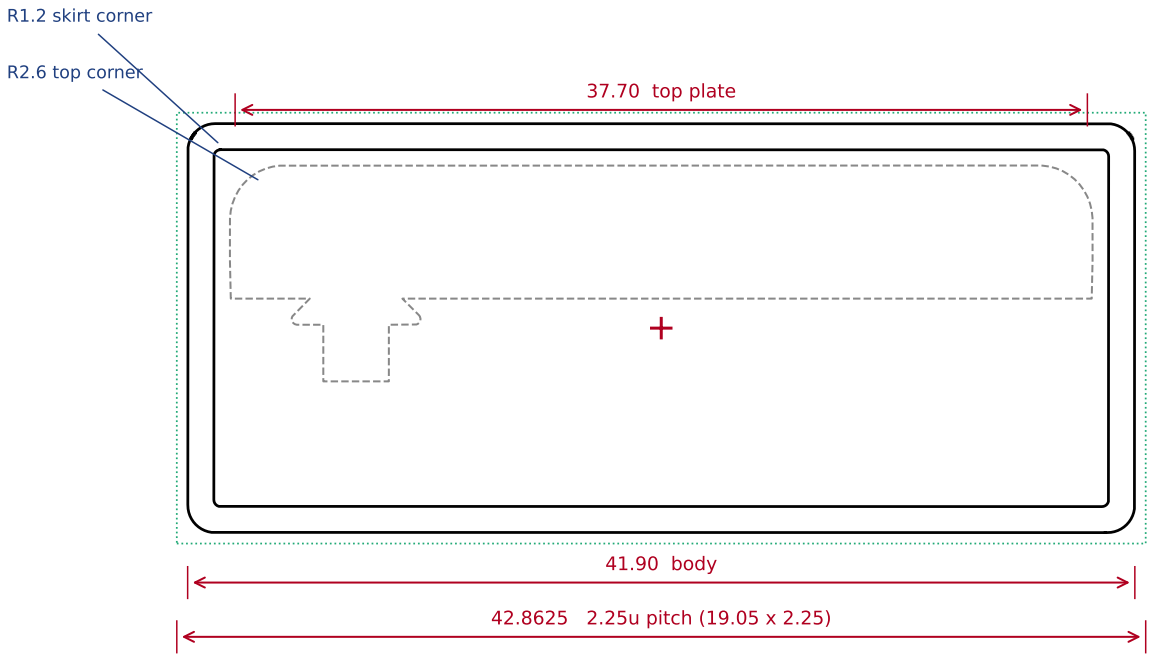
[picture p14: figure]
41.90 body; 42.8625 2.25u pitch (19.05 x 2.25); 37.70 top plate; R1.2 skirt corner; R2.6 top corner

18.10

A PLAN (top)
outline at the skirt and at the top plate

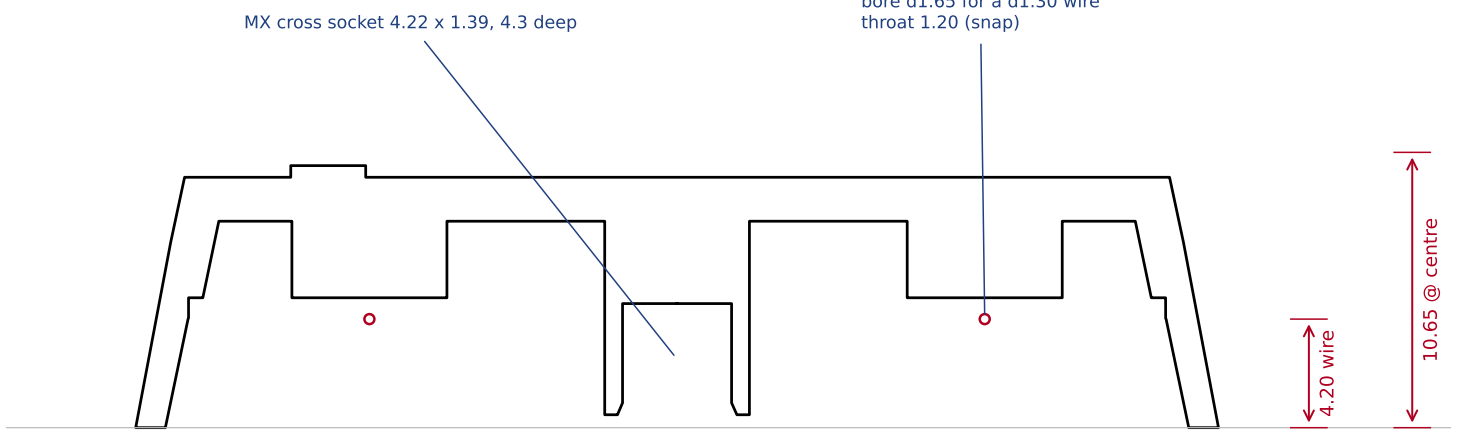
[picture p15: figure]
4.20 wire; throat 1.20 (snap); 10.65 @ centre; MX cross socket 4.22 x 1.39, 4.3 deep

23.8126 Costar stabiliser centres (1.25u) bore d1.65 for a d1.30 wire

41.90

B SECTION Y = 0 (front, through the stem and both hooks) the Costar wire runs left-right through the two bores

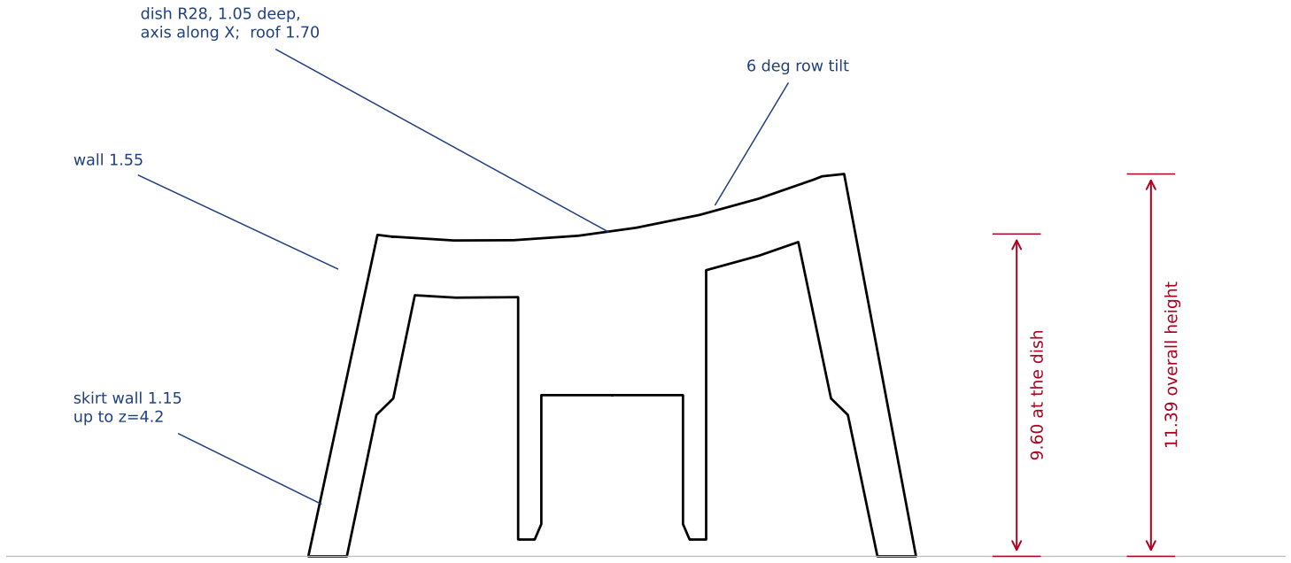
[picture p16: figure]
9.60 at the dish; 11.39 overall height; dish R28, 1.05 deep, axis along X; roof 1.70; wall 1.55; skirt wall 1.15 up to z=4.2; 6 deg row tilt
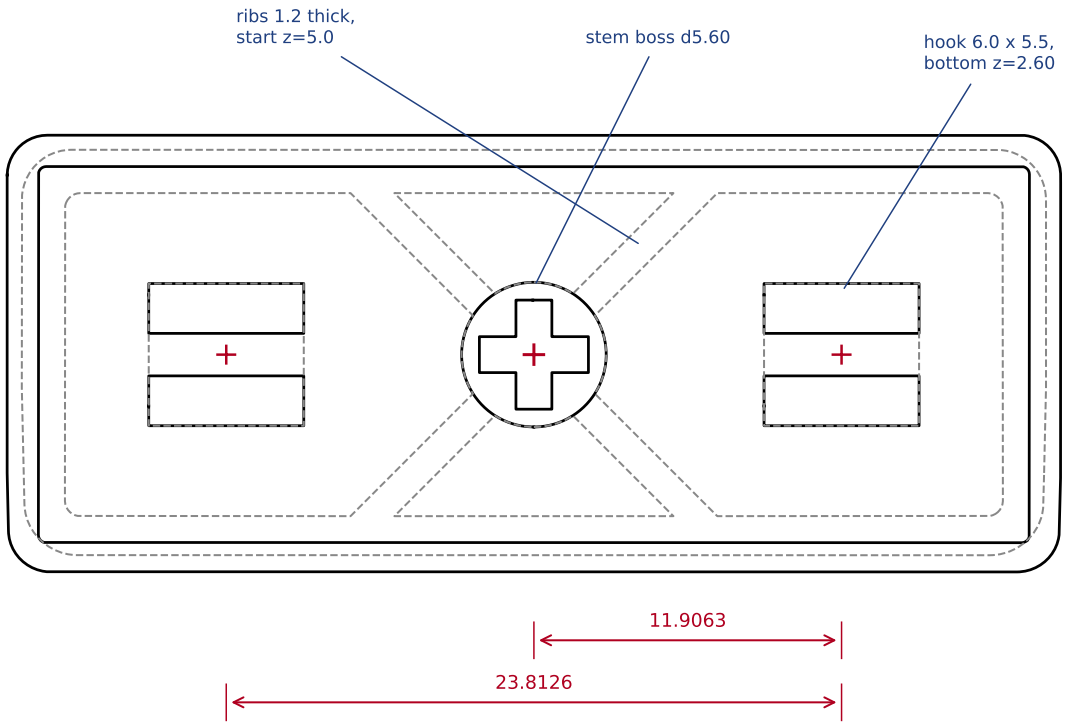
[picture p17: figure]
stem boss d5.60; ribs 1.2 thick, start z=5.0; hook 6.0 x 5.5, bottom z=2.60

18.10

C SECTION X = 0 (side, front of the keyboard to the left) OEM-style sculpt: top plate tilted back, cylindrical dish
D UNDERSIDE (section at z = 3.00, looking up) stem boss, four diagonal ribs, two Costar hook blocks ozone-strike-battle / left-shift-ansi - 2.25u, MX cross stem, Costar stabiliser | all dimensions in mm | dashed = hidden outline | dotted green = key pitch envelope

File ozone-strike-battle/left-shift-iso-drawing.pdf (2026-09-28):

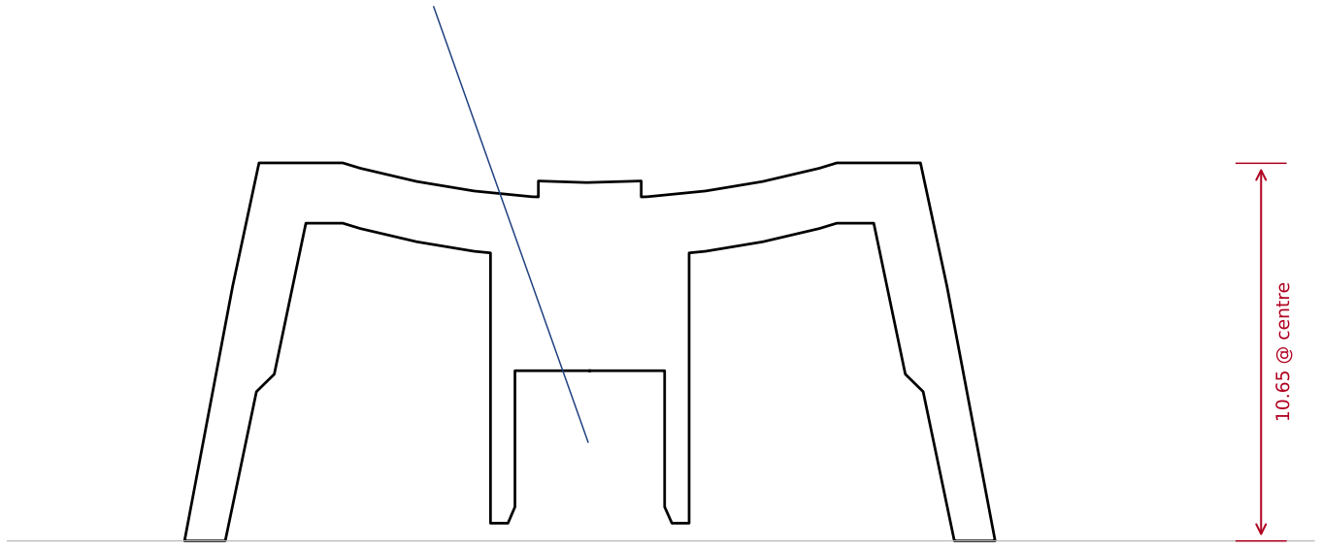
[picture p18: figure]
10.65 @ centre
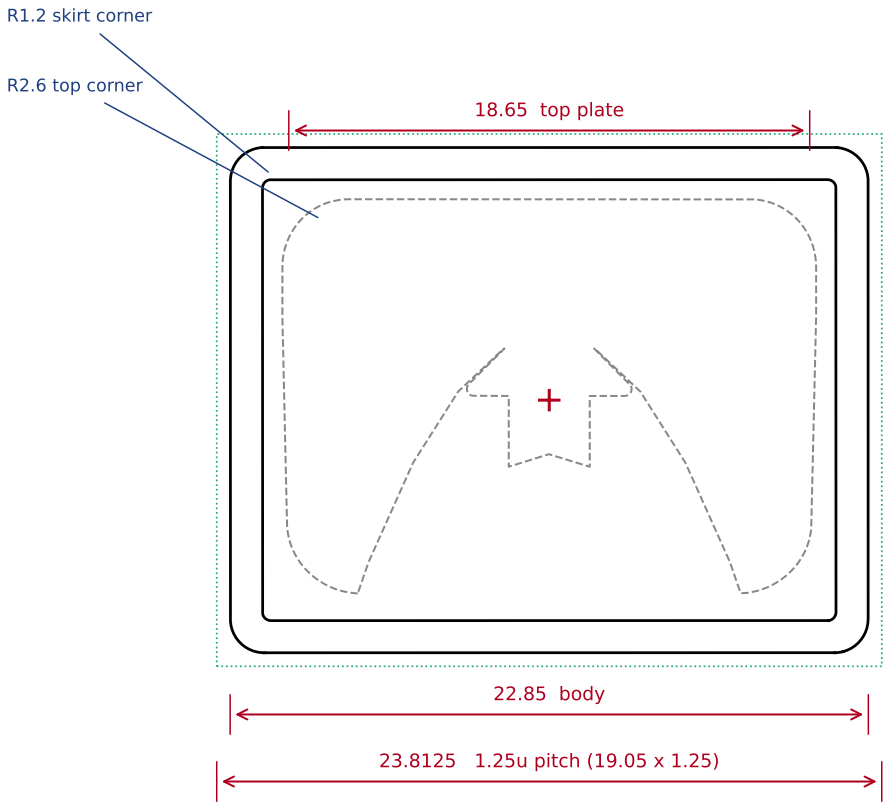
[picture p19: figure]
22.85 body; 23.8125 1.25u pitch (19.05 x 1.25); 18.65 top plate; R1.2 skirt corner; R2.6 top corner

18.10

A PLAN (top)
outline at the skirt and at the top plate

22.85

MX cross socket 4.22 x 1.39, 4.3 deep

B SECTION Y = 0 (front, through the stem)

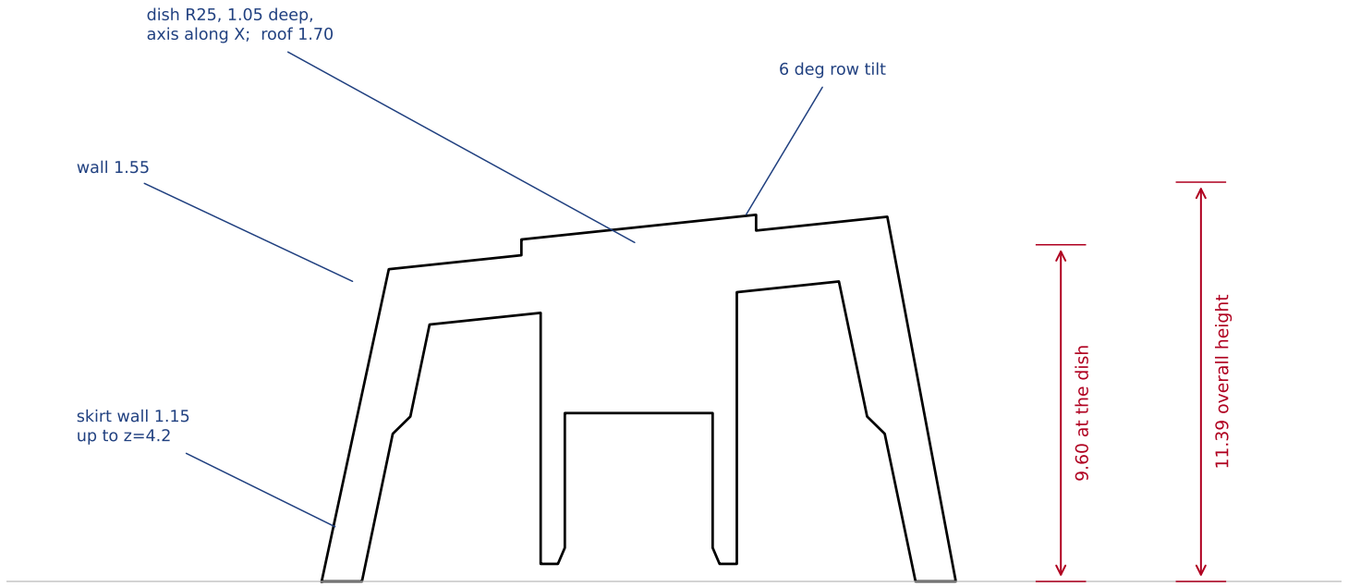
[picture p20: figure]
9.60 at the dish; 11.39 overall height; dish R25, 1.05 deep, axis along X; roof 1.70; wall 1.55; skirt wall 1.15 up to z=4.2; 6 deg row tilt

18.10

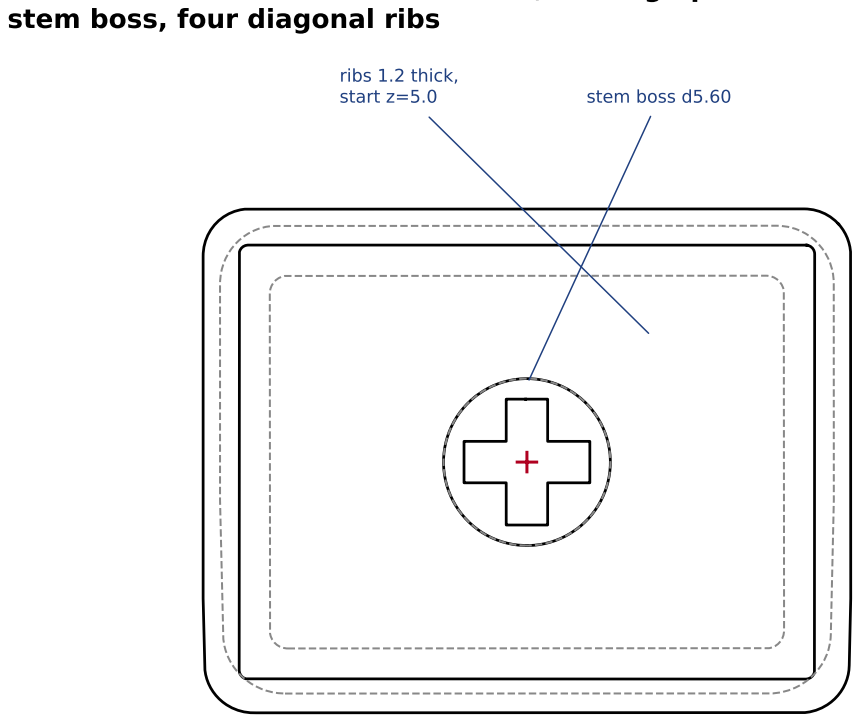
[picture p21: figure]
stem boss d5.60; ribs 1.2 thick, start z=5.0; stem boss, four diagonal ribs

C SECTION X = 0 (side, front of the keyboard to the left) OEM-style sculpt: top plate tilted back, cylindrical dish

D UNDERSIDE (section at z = 3.00, looking up) ozone-strike-battle / left-shift-iso - 1.25u, MX cross stem | all dimensions in mm | dashed = hidden outline | dotted green = key pitch envelope

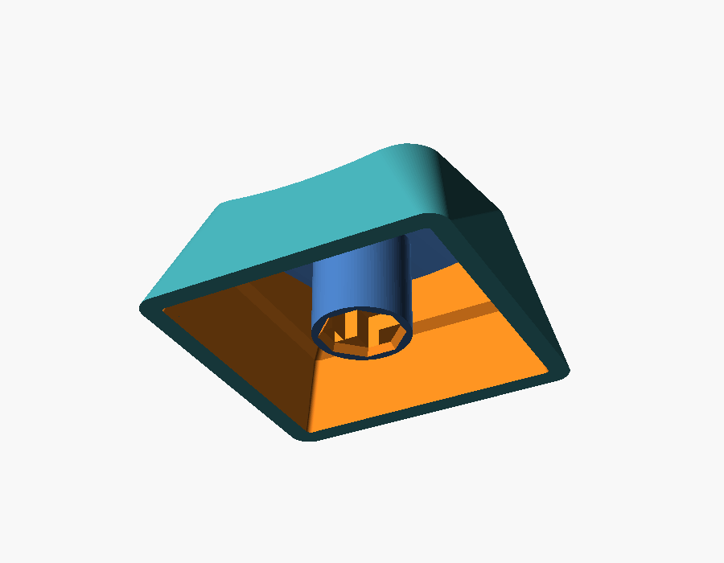
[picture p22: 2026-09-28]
asus-rog-falchion-ace/arrow-up-preview-underside.png

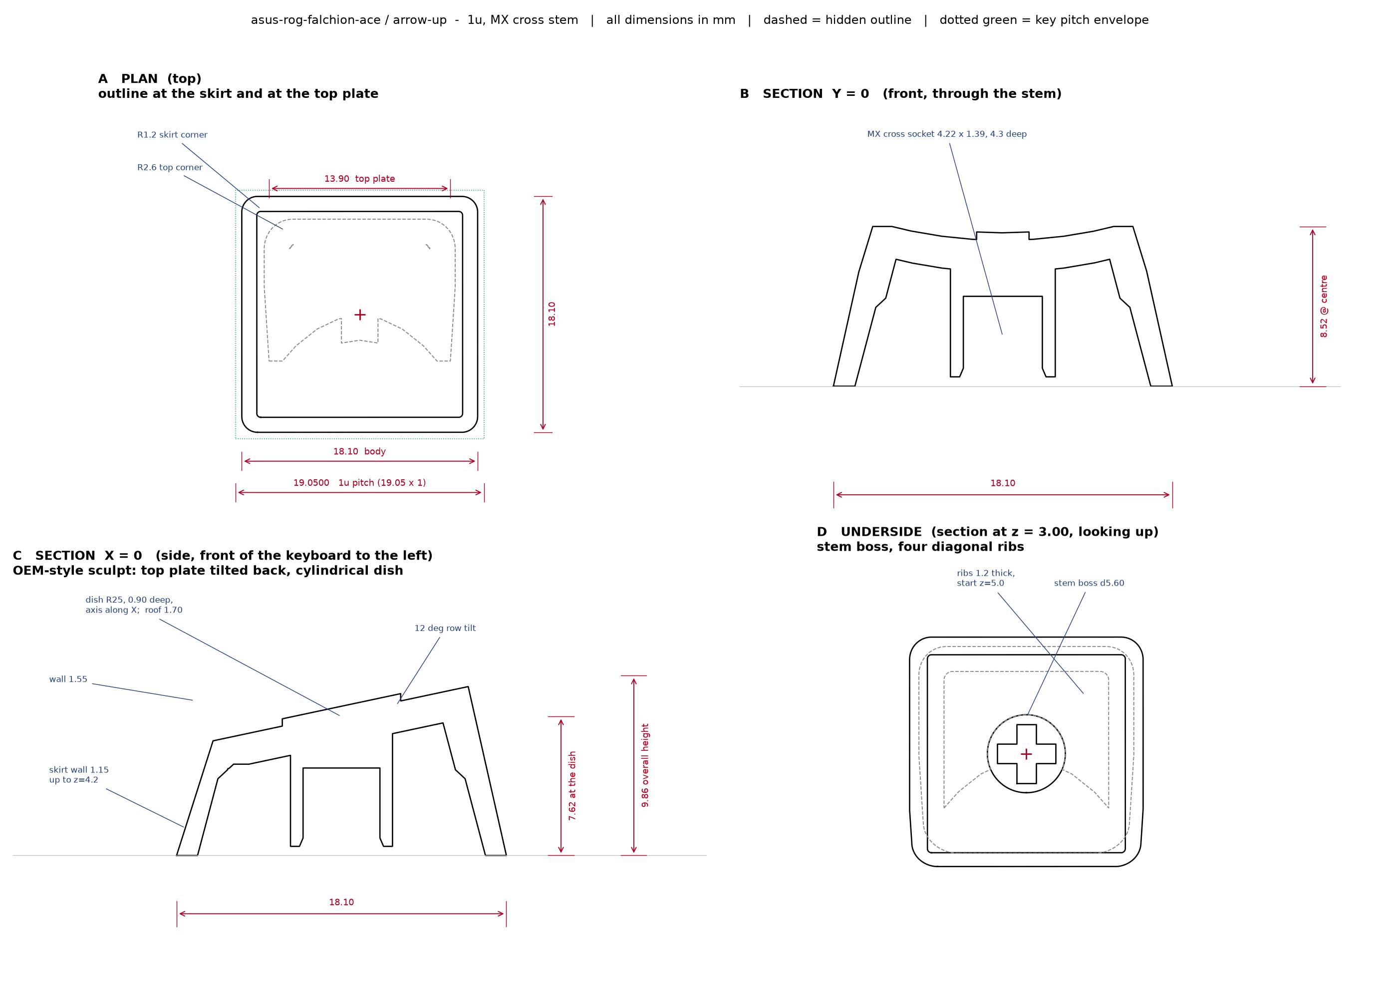
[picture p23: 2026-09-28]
asus-rog-falchion-ace/arrow-up-drawing.png

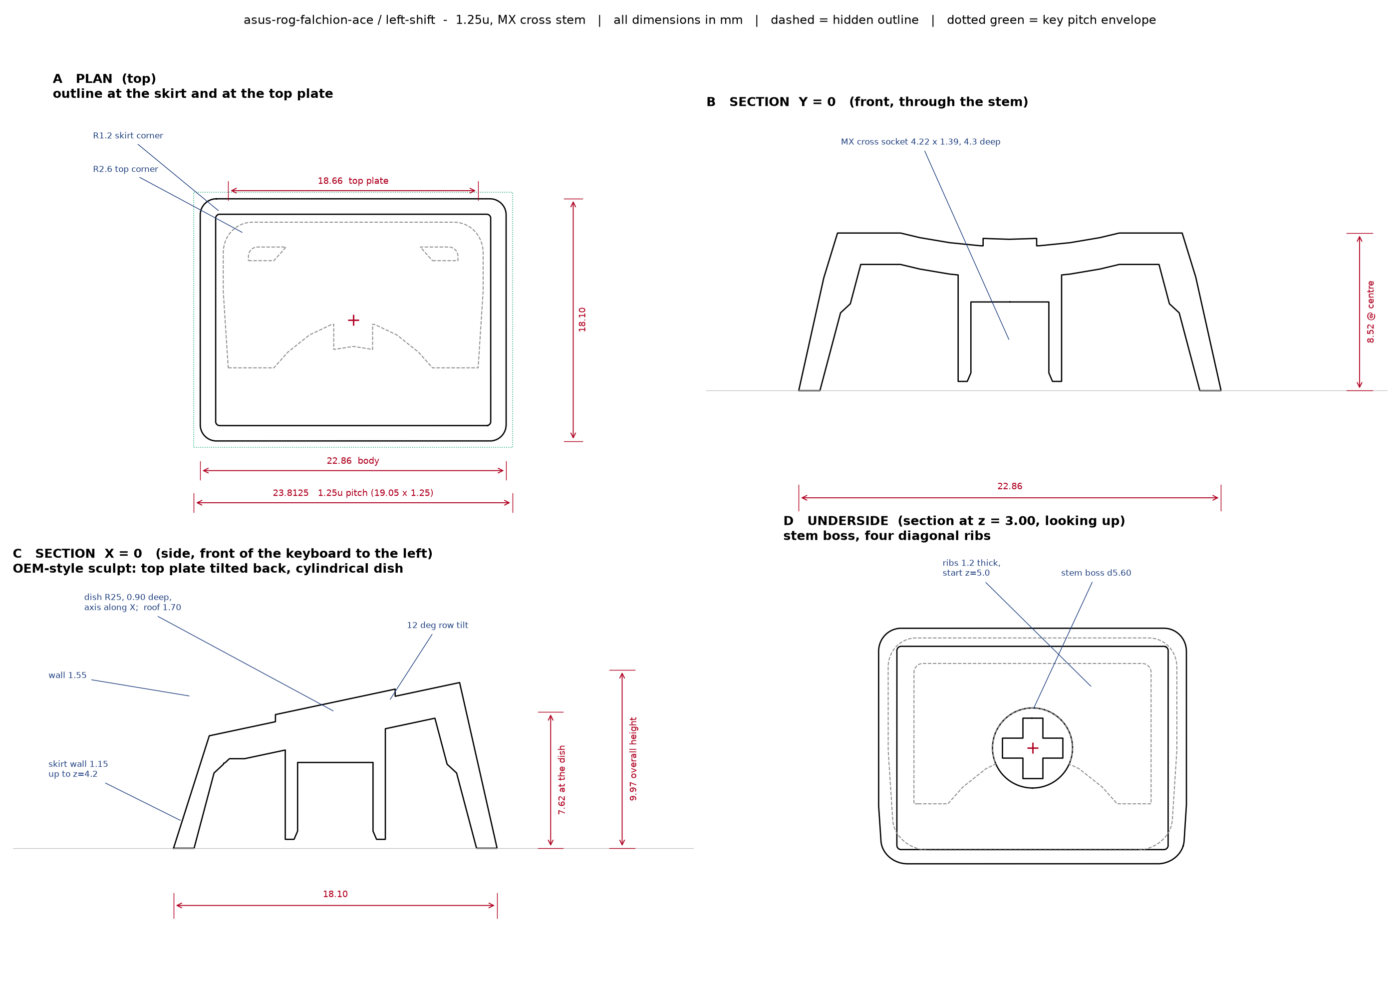
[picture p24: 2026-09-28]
asus-rog-falchion-ace/left-shift-drawing.png

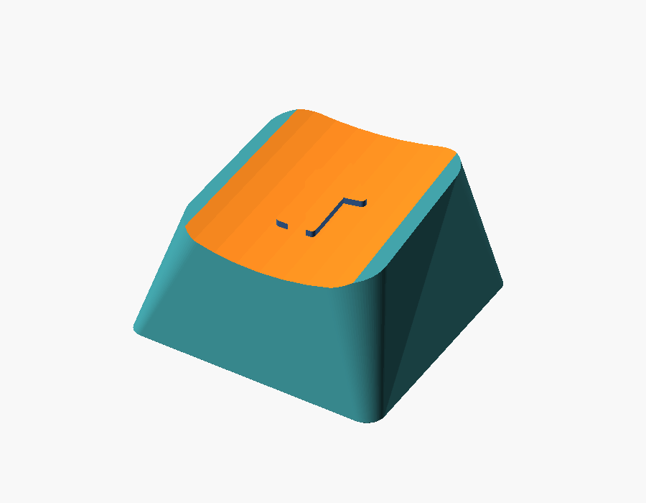
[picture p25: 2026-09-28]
asus-rog-falchion-ace/arrow-up-preview-top.png

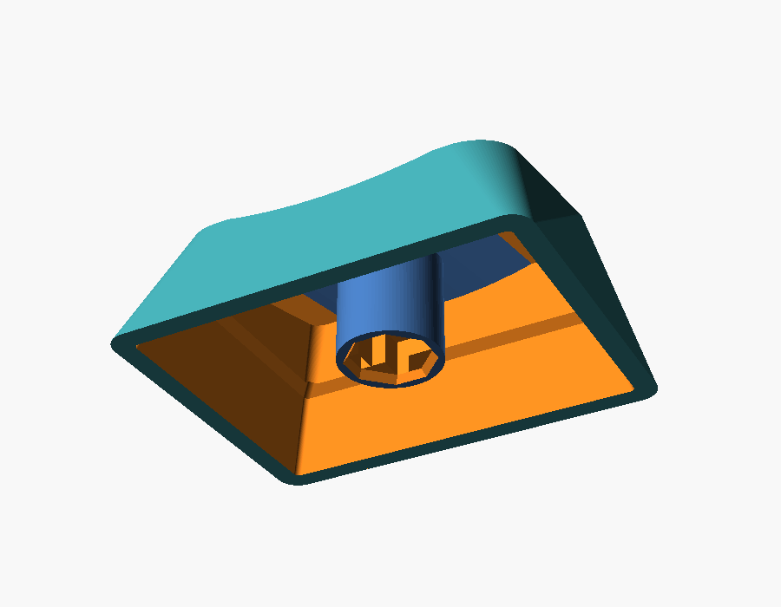
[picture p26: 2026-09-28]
asus-rog-falchion-ace/left-shift-preview-underside.png

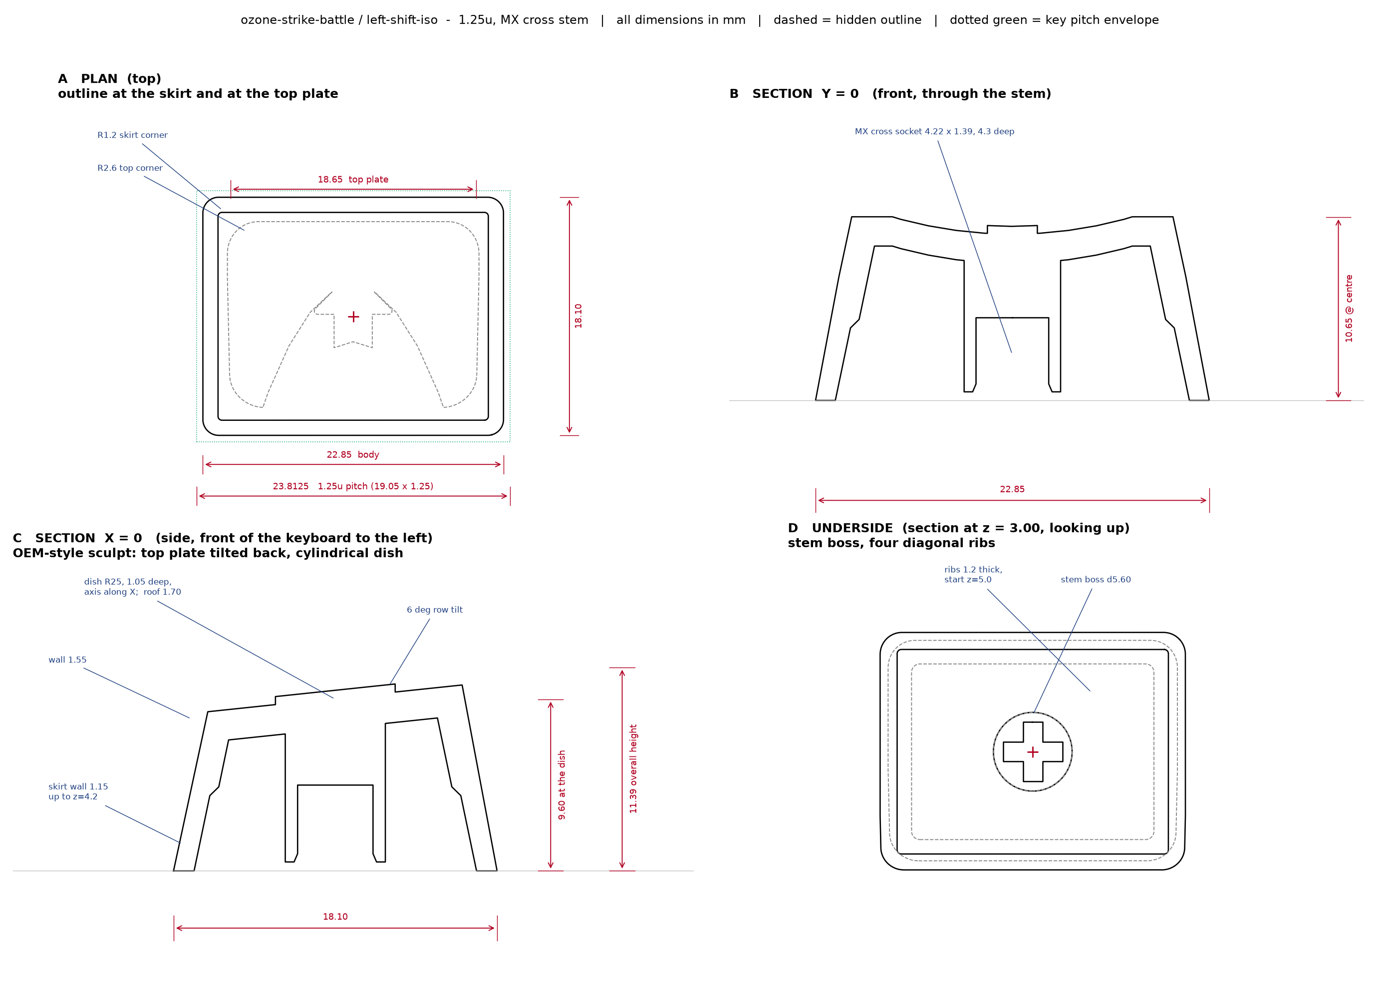
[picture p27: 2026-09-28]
ozone-strike-battle/left-shift-iso-drawing.png

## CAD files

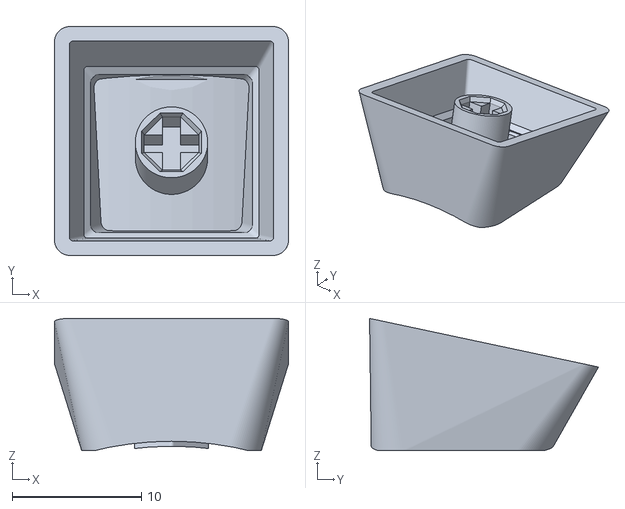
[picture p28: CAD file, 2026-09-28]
asus-rog-falchion-ace/arrow-up.stl
18.1 x 17.7 x 10.2

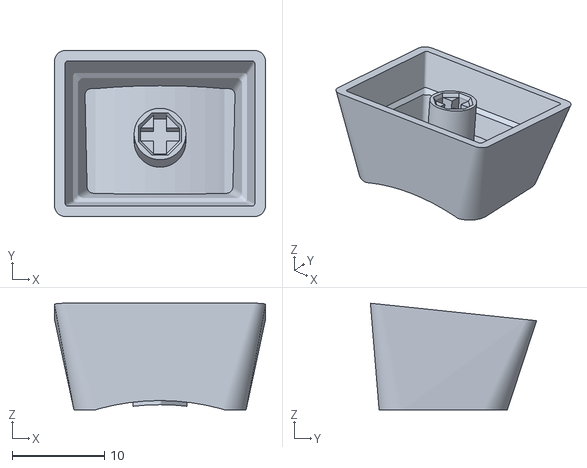
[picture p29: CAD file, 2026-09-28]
ozone-strike-battle/left-shift-iso.stl
22.9 x 18.0 x 11.5

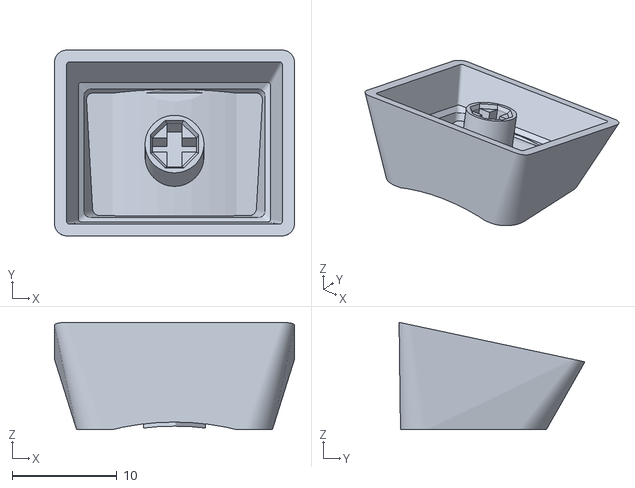
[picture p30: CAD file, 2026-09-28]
asus-rog-falchion-ace/left-shift.stl
22.9 x 17.7 x 10.2

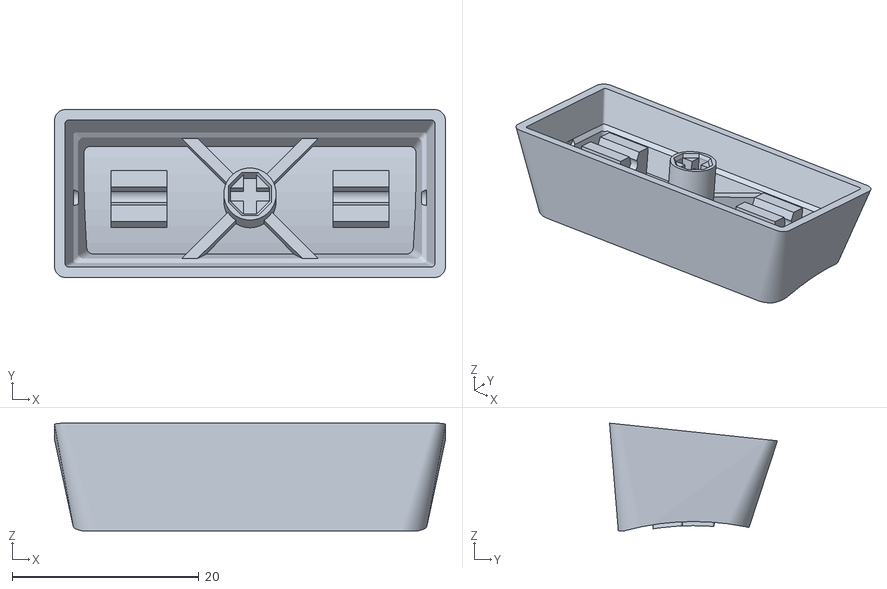
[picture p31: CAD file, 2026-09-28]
ozone-strike-battle/left-shift-ansi.stl
41.9 x 18.0 x 11.5

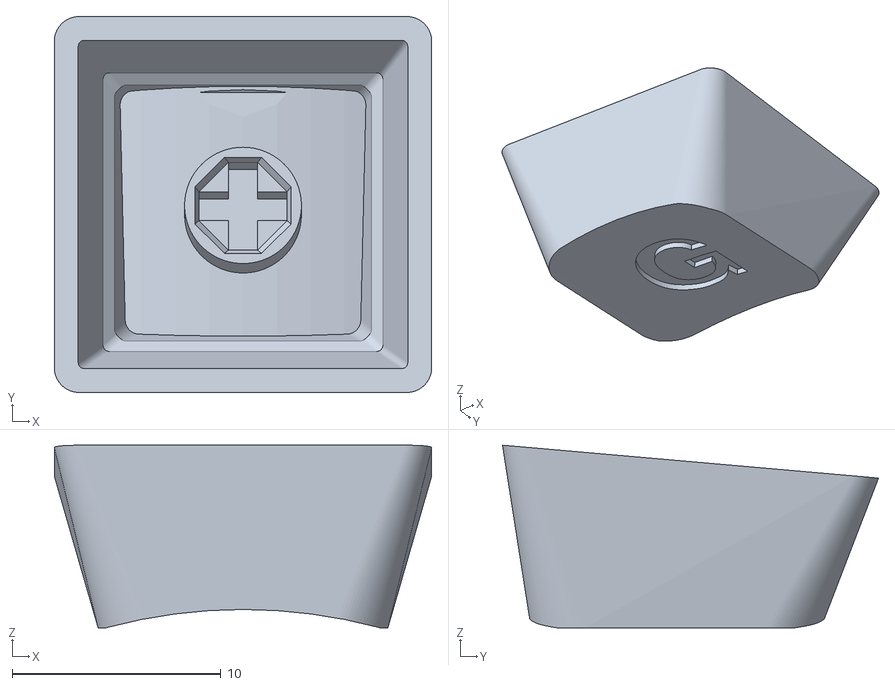
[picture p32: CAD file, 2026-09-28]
asus-rog-falchion-ace/g.stl
18.1 x 18.0 x 8.76

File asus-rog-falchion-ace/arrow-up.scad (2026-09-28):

// ============================================================================
//  ASUS ROG Falchion Ace - UP ARROW, 1u
//  ZXCV row: on a 65 % the up arrow sits to the right of the right Shift, in
//  the same row as Z X C V - confirmed on the product photo.
// ============================================================================

include <../lib/keycap_common.scad>
include <./profile.inc.scad>

units        = 1.00;
h_center     = fa_h(4);      // [EST] ZXCV row, same sculpt as the left Shift
row_tilt     = fa_tilt(4);   // [EST]
legend_mode  = "emboss";    // raised: doubles as a tactile marker for the arrows

render_keycap()
    emboss_2d(cx = 0, cy = 0, h = 0.40)
        arrow_up_2d(w = 5.2, h = 6.0, shaft = 2.3);

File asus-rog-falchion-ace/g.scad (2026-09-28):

// ============================================================================
//  ASUS ROG Falchion Ace - G, 1u
//  Home row (ASDF). Legend engraved rather than raised: it is a key you type
//  on constantly, and a raised glyph is felt under the fingertip.
// ============================================================================

include <../lib/keycap_common.scad>
include <./profile.inc.scad>

units        = 1.00;
h_center     = fa_h(3);      // [EST] home row - the lowest row of the sculpt
row_tilt     = fa_tilt(3);   // [EST]
legend_mode  = "deboss";    // engraved 0.40 mm

render_keycap()
    engrave_2d(cx = 0, cy = 0, d = 0.40)
        text("G", size = 6.2, font = fa_font(),
             halign = "center", valign = "center");

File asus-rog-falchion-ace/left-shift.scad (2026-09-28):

// ============================================================================
//  ASUS ROG Falchion Ace - LEFT SHIFT, ISO/ITA 1.25u
//  ZXCV row. NOT stabilised (unlike the ANSI 2.25u left Shift): on ISO the
//  1.25u Shift sits next to the extra <>| key, confirmed on the product photo.
// ============================================================================

include <../lib/keycap_common.scad>
include <./profile.inc.scad>

units        = 1.25;        // [SRC] ISO left Shift is 1.25u
h_center     = fa_h(4);      // [EST] ZXCV row
row_tilt     = fa_tilt(4);   // [EST]
legend_mode  = "emboss";    // raised: a tactile marker on a modifier

render_keycap()
    emboss_2d(cx = 0, cy = 0, h = 0.40)
        arrow_up_2d(w = 5.4, h = 6.2, shaft = 2.4);

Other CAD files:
asus-rog-falchion-ace/profile.inc.scad
ozone-strike-battle/left-shift-ansi.scad
ozone-strike-battle/left-shift-iso.scad
ozone-strike-battle/left-shift.scad

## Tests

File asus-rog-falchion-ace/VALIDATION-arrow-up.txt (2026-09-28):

== rendering asus-rog-falchion-ace/arrow-up.scad ==
   wrote asus-rog-falchion-ace/arrow-up.stl
== mesh integrity ==
  [PASS] watertight, single closed solid                      watertight=True bodies=1 euler=2
  [PASS] consistent winding / positive volume                 volume=957.9 mm^3 (~1.19 g PLA solid)
== outside dimensions ==
  [PASS] 1u body width (X)                                    18.100 mm  (1u pitch = 19.0500)
  [PASS] body depth (Y)                                       18.100 mm  (1u pitch = 19.05)
  [PASS] fits inside the key pitch envelope                   gap to the neighbours = 0.47 mm per side, 0.47 mm front/back
  [PASS] total height                                         9.86 mm
== MX cross stem ==
  [PASS] nominal MX cross (4.10 x 1.17) enters                interference = 0.0000 mm^3
  [PASS] socket is not oversized (+0.30 probe does clash)     interference = 3.802 mm^3 -> grip present
  [PASS] stem is centred on the key                           socket centroid X=-0.000 Y=-0.000
== switch / LED clearance ==
  [PASS] interior never tighter than a stock cap of the same sculpt worst margin +1.14 mm at z = 0.2 mm (checked to z = 5.0)
  [info] north LED column                                     not checked: led_clear_h = 0, the board lights each key with an SMD LED under the switch, nothing enters the cap
== printability ==
  [PASS] print orientation sits flat on z = 0                 min z = 0.000000
  [PASS] first layer is the top-plate rim, not a point        196 vertices within 0.25 mm of the bed
  [PASS] no overhang past 45 deg above the bed                0.0 mm^2 above the dish + 192.4 mm^2 of dish bridged over the bed
  [info] drafted walls                                        589.1 mm^2 at <=14.9 deg from vertical
   wrote asus-rog-falchion-ace/arrow-up.json

RESULT: ALL CHECKS PASSED

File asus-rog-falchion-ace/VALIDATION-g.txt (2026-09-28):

== rendering asus-rog-falchion-ace/g.scad ==
   wrote asus-rog-falchion-ace/g.stl
== mesh integrity ==
  [PASS] watertight, single closed solid                      watertight=True bodies=1 euler=2
  [PASS] consistent winding / positive volume                 volume=878.9 mm^3 (~1.09 g PLA solid)
== outside dimensions ==
  [PASS] 1u body width (X)                                    18.100 mm  (1u pitch = 19.0500)
  [PASS] body depth (Y)                                       18.100 mm  (1u pitch = 19.05)
  [PASS] fits inside the key pitch envelope                   gap to the neighbours = 0.47 mm per side, 0.47 mm front/back
  [PASS] total height                                         8.50 mm
== MX cross stem ==
  [PASS] nominal MX cross (4.10 x 1.17) enters                interference = 0.0000 mm^3
  [PASS] socket is not oversized (+0.30 probe does clash)     interference = 3.802 mm^3 -> grip present
  [PASS] stem is centred on the key                           socket centroid X=-0.000 Y=-0.000
== switch / LED clearance ==
  [PASS] interior never tighter than a stock cap of the same sculpt worst margin -0.01 mm at z = 0.2 mm (checked to z = 5.0)
  [info] north LED column                                     not checked: led_clear_h = 0, the board lights each key with an SMD LED under the switch, nothing enters the cap
== printability ==
  [PASS] print orientation sits flat on z = 0                 min z = 0.000000
  [PASS] first layer is the top-plate rim, not a point        116 vertices within 0.25 mm of the bed
  [PASS] no overhang past 45 deg above the bed                0.0 mm^2 above the dish + 193.9 mm^2 of dish bridged over the bed
  [info] drafted walls                                        555.0 mm^2 at <=15.9 deg from vertical
   wrote asus-rog-falchion-ace/g.json

RESULT: ALL CHECKS PASSED

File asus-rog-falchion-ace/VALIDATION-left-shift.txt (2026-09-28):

== rendering asus-rog-falchion-ace/left-shift.scad ==
   wrote asus-rog-falchion-ace/left-shift.stl
== mesh integrity ==
  [PASS] watertight, single closed solid                      watertight=True bodies=1 euler=2
  [PASS] consistent winding / positive volume                 volume=1158.2 mm^3 (~1.44 g PLA solid)
== outside dimensions ==
  [PASS] 1.25u body width (X)                                 22.863 mm  (1.25u pitch = 23.8125)
  [PASS] body depth (Y)                                       18.100 mm  (1u pitch = 19.05)
  [PASS] fits inside the key pitch envelope                   gap to the neighbours = 0.47 mm per side, 0.47 mm front/back
  [PASS] total height                                         9.97 mm
== MX cross stem ==
  [PASS] nominal MX cross (4.10 x 1.17) enters                interference = 0.0000 mm^3
  [PASS] socket is not oversized (+0.30 probe does clash)     interference = 3.802 mm^3 -> grip present
  [PASS] stem is centred on the key                           socket centroid X=-0.000 Y=-0.000
== switch / LED clearance ==
  [PASS] interior never tighter than a stock cap of the same sculpt worst margin +1.14 mm at z = 0.2 mm (checked to z = 5.0)
  [info] north LED column                                     not checked: led_clear_h = 0, the board lights each key with an SMD LED under the switch, nothing enters the cap
== printability ==
  [PASS] print orientation sits flat on z = 0                 min z = 0.000000
  [PASS] first layer is the top-plate rim, not a point        182 vertices within 0.25 mm of the bed
  [PASS] no overhang past 45 deg above the bed                0.0 mm^2 above the dish + 258.5 mm^2 of dish bridged over the bed
  [info] drafted walls                                        673.3 mm^2 at <=14.9 deg from vertical
   wrote asus-rog-falchion-ace/left-shift.json

RESULT: ALL CHECKS PASSED

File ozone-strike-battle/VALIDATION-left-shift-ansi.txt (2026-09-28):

/private/tmp/claude-501/-Users-allan-projects-keycaps/fa465ea8-d031-4016-8134-c6dbb5cb1e90/scratchpad/cleanvenv/lib/python3.13/site-packages/trimesh/triangles.py:302: RuntimeWarning: invalid value encountered in divide
  center_mass = integrated[1:4] / volume
== rendering ozone-strike-battle/left-shift-ansi.scad ==
   wrote ozone-strike-battle/left-shift-ansi.stl
== mesh integrity ==
  [PASS] watertight, single closed solid                      watertight=True bodies=1 euler=2
  [PASS] consistent winding / positive volume                 volume=2731.7 mm^3 (~3.39 g PLA solid)
== outside dimensions ==
  [PASS] 2.25u body width (X)                                 41.903 mm  (2.25u pitch = 42.8625)
  [PASS] body depth (Y)                                       18.100 mm  (1u pitch = 19.05)
  [PASS] fits inside the key pitch envelope                   gap to the neighbours = 0.48 mm per side, 0.47 mm front/back
  [PASS] total height                                         11.39 mm
== MX cross stem ==
  [PASS] nominal MX cross (4.10 x 1.17) enters                interference = 0.0000 mm^3
  [PASS] socket is not oversized (+0.30 probe does clash)     interference = 3.802 mm^3 -> grip present
  [PASS] stem is centred on the key                           socket centroid X=-0.000 Y=-0.000
== Costar stabiliser ==
  [PASS] wire bore clear at x=+11.906 (1.25u apart)           interference = 0.0000 mm^3
  [PASS] wire bore clear at x=-11.906 (1.25u apart)           interference = 0.0000 mm^3
  [PASS] throat (1.20 mm) open to the underside               interference = 0.0000 mm^3
  [PASS] seated wire is free to move inside the bore (+-0.15 mm) worst interference = 0.0000 mm^3
  [PASS] wire arm clears the cavity from x=+-3.2 to +-18.5    worst interference = 0.0000 mm^3 (stem boss, ribs and walls all missed)
  [PASS] throat retains the wire (interference is intentional) 0.02 mm^3 of PLA must flex to snap the wire in
== switch / LED clearance ==
  [PASS] interior never tighter than a stock cap of the same sculpt worst margin +0.00 mm at z = 0.2 mm (checked to z = 5.0)
  [PASS] north in-switch LED column (4 x 2.2, 7.0 mm tall) is clear interference = 0.0000 mm^3
== printability ==
  [PASS] print orientation sits flat on z = 0                 min z = 0.000000
  [PASS] first layer is the top-plate rim, not a point        119 vertices within 0.25 mm of the bed
  [PASS] no overhang past 45 deg above the bed                1.0 mm^2 above the dish + 532.1 mm^2 of dish bridged over the bed
  [info] drafted walls                                        1376.3 mm^2 at <=11.8 deg from vertical
   wrote ozone-strike-battle/left-shift-ansi.json

RESULT: ALL CHECKS PASSED

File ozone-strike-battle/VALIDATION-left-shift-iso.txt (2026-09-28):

== rendering ozone-strike-battle/left-shift-iso.scad ==
   wrote ozone-strike-battle/left-shift-iso.stl
== mesh integrity ==
  [PASS] watertight, single closed solid                      watertight=True bodies=1 euler=2
  [PASS] consistent winding / positive volume                 volume=1412.3 mm^3 (~1.75 g PLA solid)
== outside dimensions ==
  [PASS] 1.25u body width (X)                                 22.853 mm  (1.25u pitch = 23.8125)
  [PASS] body depth (Y)                                       18.100 mm  (1u pitch = 19.05)
  [PASS] fits inside the key pitch envelope                   gap to the neighbours = 0.48 mm per side, 0.47 mm front/back
  [PASS] total height                                         11.39 mm
== MX cross stem ==
  [PASS] nominal MX cross (4.10 x 1.17) enters                interference = 0.0000 mm^3
  [PASS] socket is not oversized (+0.30 probe does clash)     interference = 3.802 mm^3 -> grip present
  [PASS] stem is centred on the key                           socket centroid X=-0.000 Y=-0.000
== switch / LED clearance ==
  [PASS] interior never tighter than a stock cap of the same sculpt worst margin +0.00 mm at z = 0.2 mm (checked to z = 5.0)
  [PASS] north in-switch LED column (4 x 2.2, 7.0 mm tall) is clear interference = 0.0000 mm^3
== printability ==
  [PASS] print orientation sits flat on z = 0                 min z = 0.000000
  [PASS] first layer is the top-plate rim, not a point        114 vertices within 0.25 mm of the bed
  [PASS] no overhang past 45 deg above the bed                0.0 mm^2 above the dish + 259.9 mm^2 of dish bridged over the bed
  [info] drafted walls                                        829.9 mm^2 at <=11.8 deg from vertical
   wrote ozone-strike-battle/left-shift-iso.json

RESULT: ALL CHECKS PASSED

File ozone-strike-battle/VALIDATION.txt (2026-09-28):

== rendering ozone-strike-battle/left-shift.scad ==
   wrote ozone-strike-battle/left-shift.stl
== mesh integrity ==
  [PASS] watertight, single closed solid                      watertight=True bodies=1 euler=2
  [PASS] consistent winding / positive volume                 volume=2731.7 mm^3 (~3.39 g PLA solid)
== outside dimensions ==
  [PASS] 2.25u body width (X)                                 41.903 mm  (2.25u pitch = 42.8625)
  [PASS] body depth (Y)                                       18.100 mm  (1u pitch = 19.05)
  [PASS] fits inside the key pitch envelope                   gap to the neighbours = 0.48 mm per side, 0.47 mm front/back
  [PASS] total height                                         11.39 mm
== MX cross stem ==
  [PASS] nominal MX cross (4.10 x 1.17) enters                interference = 0.0000 mm^3
  [PASS] socket is not oversized (+0.30 probe does clash)     interference = 3.802 mm^3 -> grip present
  [PASS] stem is centred on the key                           socket centroid X=-0.000 Y=-0.000
== Costar stabiliser ==
  [PASS] wire bore clear at x=+11.906 (1.25u apart)           interference = 0.0000 mm^3
  [PASS] wire bore clear at x=-11.906 (1.25u apart)           interference = 0.0000 mm^3
  [PASS] throat (1.20 mm) open to the underside               interference = 0.0000 mm^3
  [PASS] seated wire is free to move inside the bore (+-0.15 mm) worst interference = 0.0000 mm^3
  [PASS] wire arm clears the cavity from x=+-3.2 to +-18.5    worst interference = 0.0000 mm^3 (stem boss, ribs and walls all missed)
  [PASS] throat retains the wire (interference is intentional) 0.02 mm^3 of PLA must flex to snap the wire in
== switch / LED clearance ==
  [PASS] interior never tighter than a stock OEM cap (front/back) worst margin +0.01 mm at z = 0.2 mm
  [PASS] north in-switch LED column (4 x 2.2 @ y=2.9..5.1) is clear interference = 0.0000 mm^3
== printability ==
  [PASS] print orientation sits flat on z = 0                 min z = 0.000000
  [PASS] first layer is the top-plate rim, not a point        119 vertices within 0.25 mm of the bed
  [PASS] no cantilevered overhang above the bed               4.6 mm^2 (bore roofs) + 532.1 mm^2 of dish bridged over the bed
  [info] drafted walls                                        1372.7 mm^2 at <=11.8 deg from vertical

RESULT: ALL CHECKS PASSED

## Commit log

2026-09-28 feat: repo keycap parametrici — libreria condivisa + Ozone Strike Battle left Shift
    Prima release della repo. Struttura pensata per riusare tutto il lavoro
    comune sul prossimo progetto (ASUS ROG Falchion Ace, layout ITA).
    - lib/keycap_common.scad: geometria condivisa (guscio, dish, sculpt OEM,
    socket a croce MX, hook Costar integrato, nervature, legend in rilievo).
    Parametri con default sovrascrivibili dal file della singola chiave.
    - tools/: build+validazione (20 probe booleani, non controlli a occhio),
    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
    [left-shift.scad, left-shift.stl]
2026-09-28 fix(make): il target validate escludeva lib/ solo per caso — ora esplicito
    `wildcard */*.scad` pescava anche lib/keycap_common.scad, che non ha
    geometria top-level: openscad rispondeva "Current top level object is empty"
    e veniva scritto un lib/VALIDATION.txt senza senso.
2026-09-28 feat(falchion): Shift sinistro ISO 1.25u, G e freccia Su — ITA, tutti validati
    Tre tasti, nessuno stabilizzato, quindi il blocco sullo stabilizzatore Cherry
    non si presenta. Confermato dalla foto del prodotto girata dall'utente: Shift
    sinistro 1.25u col tasto <>| accanto, freccia Su sulla fila ZXCV, Enter ISO.
    La foto e' la variante DE ma il layout fisico e' lo stesso dell'ITA, e per
    questi tre tasti i glifi coincidono.
    Fonti: lo stelo ROG NX e' a croce MX-compatibile (ASUS), e gli LED per-tasto
    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
    [arrow-up.scad, arrow-up.stl, g.scad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]
2026-09-28 docs: licenza MIT
    Repo pubblica: senza una licenza nessuno puo' formalmente riusare o
    modificare i file, anche vedendoli. MIT copre sorgenti, tooling e STL.
    Nel README la nota che conta: niente garanzia, e qui pesa piu' del solito
    perche' in ogni modello ci sono quote stimate, elencate una per una.
2026-09-28 fix(ozone): la tastiera dell'utente e' ISO — aggiunto lo Shift sinistro 1.25u
    La foto della sua Strike Battle mostra il tasto <> accanto allo Shift sinistro
    e l'Enter a L: e' una ISO, non una ANSI. Sull'ISO lo Shift sinistro e' 1.25u e
    NON e' stabilizzato, quindi il cap ANSI 2.25u con gli hook Costar non entra
    sulla sua tastiera.
    Il brief iniziale diceva esplicitamente ANSI 2.25u con stabilizzatore 2u, e
    quel modello resta corretto rispetto a quanto specificato: lo tengo come
    left-shift-ansi.*. Il nuovo left-shift-iso.* e' 1.25u, stab_style="none",
    dish concavo sinistra-destra come gli alfanumerici (il 2.25u usa l'asse lungo).
    Il cap ISO e' anche il piu' semplice dei due: senza stabilizz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
    [left-shift-ansi.scad, left-shift-ansi.stl, left-shift-iso.scad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]
2026-09-28 docs(ozone): confermato ISO italiana
    Nessuna modifica al modello: ITA, UK e DE condividono lo Shift sinistro da
    1.25u, cambia solo il glifo sul tasto accanto (<> contro \|). Un cap copre
    tutti e tre.
    [left-shift-iso.scad]
2026-09-28 ci: validate come merge gate + self-test che dimostra che i check sanno fallire
    validate.yml: scopre da solo i .scad (nessuna lista da mantenere), matrice per
    tasto, suite completa, e verifica che l'STL committato corrisponda ancora al
    modello — il caso «ho toccato lo .scad e non ho rigenerato». Il confronto e'
    su bounding box e volume, non sui byte: tassellazione e sostituzione dei font
    differiscono tra Mac e runner, un confronto binario sarebbe rosso per sempre.
    Job lint in parallelo (ogni tasto ha STL, report e README) e bundle degli STL
    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
2026-09-28 ci: l'AppImage OpenSCAD ha bisogno dello stack GL/EGL di sistema
    Primo giro rosso su tutti e 5 i tasti, exit 127: 'libEGL.so.1: cannot open
    shared object file'. Un AppImage impacchetta le librerie dell'applicazione ma
    per progetto si aspetta che GL/EGL li fornisca il sistema, e il runner
    ubuntu-latest non li ha.
    Aggiunto il runtime Qt/GL all'apt, e QT_QPA_PLATFORM=offscreen: l'export in
    STL non serve un display, ma Qt un platform plugin lo vuole comunque.
    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
2026-09-28 ci: requirements.txt era incompleto — mancavano scipy e networkx
    Secondo giro rosso: OpenSCAD 2026.09.27 parte e Manifold c'e', ma il
    validatore muore al primo check con ModuleNotFoundError: scipy. trimesh li usa
    a runtime (scipy per body_count, networkx per split) senza dichiararli.
    Invece di aggiungerli e sperare, ho ricostruito un venv pulito dal solo
    requirements.txt: 5 tasti su 5 verdi, self-test verde, disegni generati. La
    lista adesso e' verificata, non dedotta.
2026-09-28 ci: disegni riproducibili byte-per-byte
    matplotlib incorporava la data di creazione in ogni PDF e SVG, quindi
    rigenerare un disegno immutato risultava comunque come un diff e la domanda
    «l'artefatto committato e' aggiornato?» diventava senza risposta. Ora niente
    data e hashsalt fisso: due generazioni di fila non producono differenze
    (verificato).
2026-09-28 feat(pages): catalogo su GitHub Pages, generato dall'output del validatore
    https://allan-nava.github.io/keycaps/ — ogni modello con quote, peso in PLA,
    disegno, anteprima del sottocap e download diretto dell'STL.
    La pagina NON e' scritta a mano: build_and_validate.py ora emette anche un
    <tasto>.json accanto al report testuale (quote misurate, volume, esito di ogni
    singolo check, parametri), e make_site.py costruisce l'HTML da quello. Cosi'
    la pagina non puo' affermare una quota che i controlli non hanno misurato, e
    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
2026-10-02 docs: il primo cap stampato, con l'onesta' su cosa dimostra
    Finora il repo aveva solo verifiche geometriche: si renderizza un solido, si
    spingono dentro delle sonde booleane, si registrano i numeri. Prende molto —
    un socket che non accetterebbe una croce MX, un cap piu' largo del suo passo,
    uno sbalzo che vorrebbe supporti — e non prende niente di cio' che esiste solo
    quando la plastica si raffredda.
    photos/ tiene le foto separate dall'output di validazione apposta: una foto
    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
